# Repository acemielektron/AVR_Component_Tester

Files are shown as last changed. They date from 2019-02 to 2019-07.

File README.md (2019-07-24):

# AVR_Component_Tester
DIY single sided PCB for AVR Component Tester (based on pdf file by Karl-Heinz Kübbeler)

A very useful gadget whether you buy from many clones available or build it yourself. Here is my version:

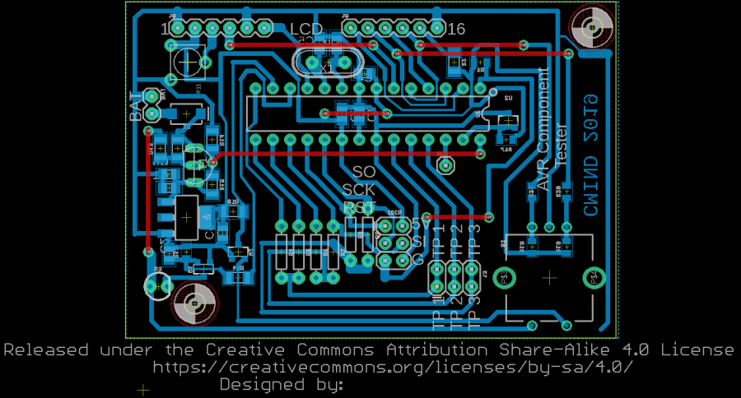
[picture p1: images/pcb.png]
pcb</img>

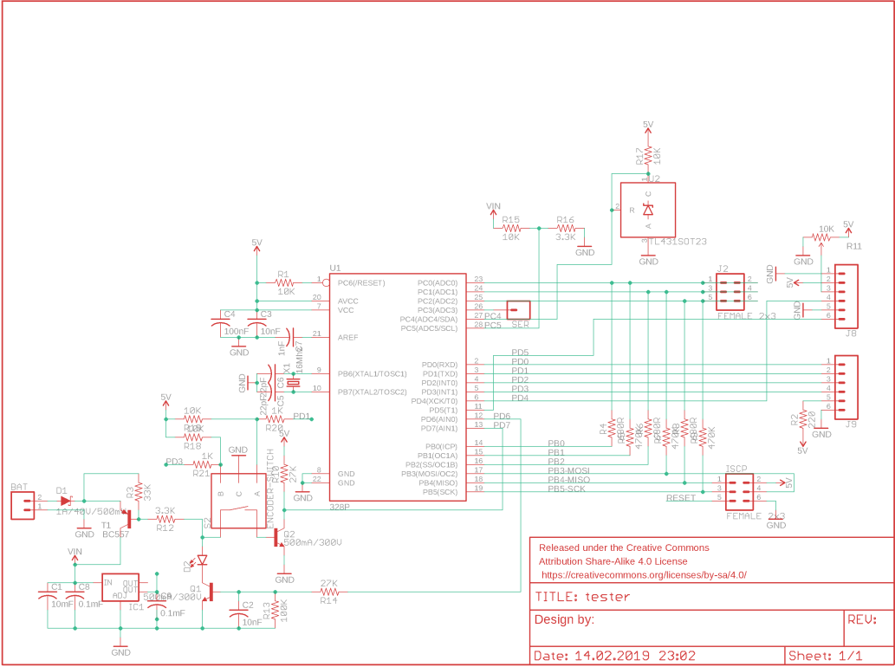
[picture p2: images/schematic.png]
schematic</img>

photos of built device:
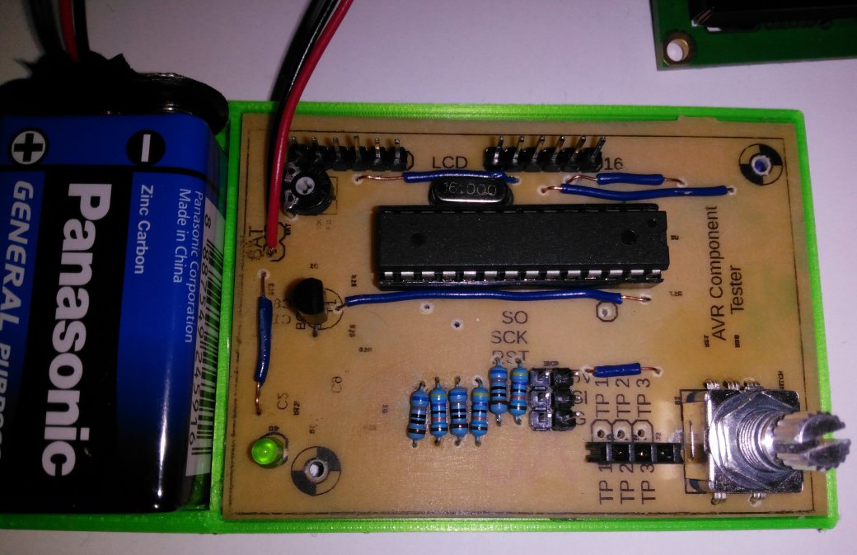
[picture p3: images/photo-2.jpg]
without 2x16 lcd screen</img>

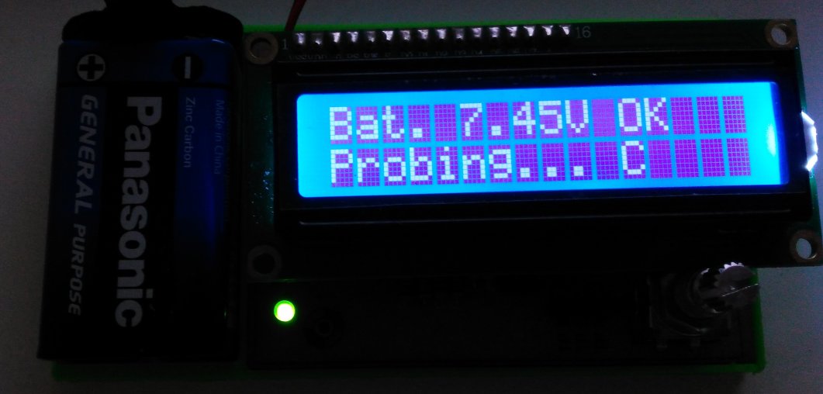
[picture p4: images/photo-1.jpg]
screen installed and working</img>

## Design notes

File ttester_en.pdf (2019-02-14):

# TransistorTester with AVR microcontroller and a little more Version 1.13k

### Karl-Heinz K¨ubbeler

kh kuebbeler@web.de

### March 8, 2018

# Contents

1 Features | 5
2 Hardware | 9
3 Instructions for use | 39
4 Configuring the TransistorTester | 48

5 Description of the measurement procedures | 60
5.1 Measurement of Semiconductors | 62
5.1.1 | Measurement of PNP Transistor or P-Channel-MOSFET | 63
5.1.2 | Measurement of NPN Transistor or N-Channel-MOSFET | 65
5.1.3 | Simplified flowchart of the transistors tests | 68
5.1.4 | Measurement of Diodes | 70
5.1.5 | Results of different measurements | 71
5.2 Resistor Measurement | 75
5.2.1 | Resistor Measurement with 680 Ohm Resistors | 75
5.2.2 | Resistor Measurement with 470 kOhm resistors | 77
5.2.3 | Results of the resistor measurements | 78
5.3 Measurement of Capacitors | 83
5.3.1 | Discharging of Capacitors | 83
5.3.2 | Measurement of big Capacitors | 83
5.3.3 | Measurement of small Capacitors | 86
5.3.4 | Measurement of very small capacity values with the sampling technique . . . . 88
5.3.5 | Measurement of the Equivalent Series Resistance ESR | 89
5.3.6 | Measurement of the Equivalent Series Resistance ESR, first way | 91
5.3.7 | Measurement of the Equivalent Series Resistance ESR, second way | 94
5.3.8 | Voltage loss after a load pulse, Vloss | 101
5.3.9 | Separate capacity and ESR measurement | 102
5.3.10 Results of Capacitor measurement | 103
5.3.11 Automatic calibration of the capacitor measurement | 107
5.4 Measurement of inductance | 111
5.4.1 | Results of the inductance measurements | 112
5.4.2 | Measurement of small inductances with the sampling method | 112
5.5 Selftest Function | 116
5.5.1 Some Results of the Selftest Function | 120
5.6 Measurement of frequency | 124
5.6.1 | Calibration of frequency with a GPS- or GLONASS-receiver | 125
5.6.2 | Calibration of the crystal frequency with a clock modul | 125
6 Signal generation | 127
6.1 Frequency Generation | 127
6.2 Puls width generation | 127
7 Known errors and unsolved problems | 128
8 Special Software Parts | 129
9 To Do List and new ideas | 130

## Preface

### Basically Motive

Every hobbyist knows the following problem: You disassemle a Transistor out of a printed board or you get one out of a collection box. If you find out the identification number and you already have a data sheet or you can get the documents about this part, everything is well. But if you don’t find any documents, you have no idea, what kind of part this can be. With conventional approach of measurement it is difficult and time-consuming to find out the type of the part and parameters. It could be a NPN, PNP, N- or P-Channel-Mosfet etc. It was the idea of Markus F. to hand over the work to a AVR microcontroller.

### As my work has started

My work with the software of the TransistorTester of Markus F. [1] has started, because I had problems with my programmer. I had bought a printed board and components, but I could not program the EEprom of the ATmega8 with the Windows driver without error messages. Therefore I took the software of Markus F. and changed all the accesses from the EEprom memory to flash memory accesses. By analysing the software in order to save memory at other places of program, I had the idea, to change the result of the ReadADC function from ADC units to millivolt (mV) units. The mV resolution is needed for any output of voltage values. If ReadADC returns directly the mV resolution, I can save the conversion for each output value. This mV resolution can be get, if you first accumulate the results of 22 ADC readings. The sum must be multiplied with two and divided by nine. Then we have a maximum value of 1023·22·2
9 = 5001, which matches perfect to the wanted mV resolution of measured voltage values. So I additionally had the hope, that the enhancement of ADC resolution by oversampling could help to improve the voltage reading of the ADC, as described in AVR121 [5]. The original version ReadADC has accumulated the result of 20 ADC measurements and divides afterwards by 20, so the result is equal to original ADC resolution. By this way never a enhancement of ADC resolution can take place. So I had to do little work to change the ReadADC, but this forced analysing the whole program and change of all “if-statements” in the program, where voltage values are queried. But this was only the beginning of my work!

More and more ideas to make measurement faster and more accurate has been implemented. Additionally the range of resistor and capacity measurements are extended. The output format for LCD-Display was changed, so symbols are taken for diodes, resistors and capacitors instead of text. For further details take a look to the actual feature list chapter 1. Planned work and new ideas are accumulated in the To Do List in chapter 9. By the way, now I can program the EEprom of the ATmega with Linux operating system without errors.
At this place I would like to thank the originator and software author Markus Frejek, who has enabled the continuation with his initial work. In addition I would like to say thanks to the authors of numerous input to the discussion forum, which have assist me, to find new tasks, weak points and errors. Next I would like to thank Markus Reschke, who give me the permission, to publish his cheerful software versions at the SVN server. Furthermore some ideas and software part of Markus R. was integrated in my own software version, again thank you very much. Also Wolfgang SCH. has done a great job to support a graphical display with ST7565 controller. Many thanks to him for integrating his patch for 1.10k software version to the actual developer version. I have to thank also Asco B., who has developed a new printed board, to enable the reproductions for other hobbyists. Another thank I would like to send to Dirk W. , who has handled the omnibus order for this printed board. Never I had time anough to handle these things concurrently with my software developement, at no time the state of further developement of software would have the same level. Thanks for the many suggestions to improve the tester to the members of the local chapter of the

”Deutscher Amateur Radio Club (DARC)” in Lennestadt. Also I would like to say thanks for the integration of the sampling method to the radio amateur Pieter-Tjerk (PA3FWM). With this method the measurement of little capacity and inductance values could be improved noticeable. Last but not least I would say thanks to Nick L. from Ukraine, who has supported my with his prototype boards, has suggested some hardware add ons and also has organized the russian translation for this description.

# Chapter 1

# Features

1. Operates with ATmega8, ATmega168 or ATmega328 microcontrollers. Additionally ATmega644, ATmega1284, ATmega1280 or ATmega2560 microcontrollers can be used.
2. Displaying the results to a 2x16 or a 4x16 character LCD-Display. If the processor have at least 32K flash memory, also a graphical display with 128x64 pixel and a ST7565, ST7920, NT7108, KS0108 or a SSD1306 controller can be used. In doing so a 4-wire SPI interface or a I

2C bus must be used instead of the 4-bit parallel interface for the SSD1306 controller. Even color displays with ILI9163 or ST7735 controller are usable with the SPI interface. For the NT7108 or KS0108 controller you must use a serial - parallel interface with a 74HC(T)164 or a 74HC(T)595. Displays with PCF8812 or PCF8814 controller can be only used without the big icons for transistors, because the display size is unsufficient (102x65 and 96x65).

3. One key operation with automatic power shutdown.
4. Battery operation is possible since shutdown current is only about 20nA.
5. Low cost version is feasible without crystal and auto power off. With software version 1.05k the sleep modus of the Atmega is used to reduce current if no measurement is required and no rotary encoder is used (not with ATmega8).
6. Automatic detection of NPN and PNP bipolar transistors, N- and P-Channel MOSFETs, JFETs, diodes, double diodes,N- and P-IGBTs, Thyristors and Triacs. For Thyristors and Triacs the ignition current and holding current must be reached with the tester. For IGBTs the 5V signal should be enough for driving the gate voltage.
7. Automatic detection of pin layout of the detected part.
8. Measuring of current amplification factor and Base-Emitter threshold voltage of bipolar transistors.
9. Darlington transistors can be identified by the threshold voltage and high current amplification factor.
10. Detection of the protection diode of bipolar transistors and MOSFETs.
11. Measuring of the Gate threshold voltage, the Gate capacity value and the RDSon at almost 5V gate voltage of MOSFETs.
12. Up to two Resistors are measured and shown with symbols | and values with up to four
decimal digits in the right dimension. All symbols are surrounded by the probe numbers of the Tester (1-3). So Potentiometer can also be measured. If the Potentiometer is adjusted to one of its ends, the Tester cannot differ the middle pin and the end pin.

13. Resolution of resistor measurement is now up to 0.01Ω, values up to 50MΩ are detected.
14. One capacitor can be detected and measured. It is shown with symbol | and value with
up to four decimal digits in the right dimension. The value can be from 25pF (8MHz clock, 50pF @1MHz clock) to 100mF. The resolution can be up to 1pF (@8MHz clock].
15. For capacitors with a capacity value above 20nF the Equivalent Serial Resistance (ESR) is measured with a resolution of 0.01Ω and is shown with two significant decimal digits. This feature is only available for ATmega with at least 16K flash memory.
16. For capacitors with a capacity value above 5000pF the voltage loss after a load pulse can be determined. The voltage loss give a hint for the quality factor of the capacitor.
17. Up to two diodes are shown with symbol | or symbol | in correct order. Additionally
the flux voltages are shown.
18. LED is detected as diode, the flux voltage is much higher than normal. Two-in-one LEDs are also detected as two diodes.
19. Zener-Diodes can be detected, if reverse break down Voltage is below 4.5V . These are shown as two diodes, you can identify this part only by the voltages. The outer probe numbers, which surround the diode symbols, are identical in this case. You can identify the real Anode of the diode only by the one with break down (threshold) Voltage nearby 700mV !
20. If more than 3 diode type parts are detected, the number of founded diodes is shown additionally to the fail message. This can only happen, if Diodes are attached to all three probes and at least one is a Z-Diode. In this case you should only connect two probes and start measurement again, one after the other.
21. Measurement of the capacity value of a single diode in reverse direction. Bipolar Transistors can also be analysed, if you connect the Base and only one of Collector or Emitter. If a ATmega with more than 8K flash memory is used, also the reverse current of the diode is measured with a resolution of 2nA. The value is only output to the screen, if it is greater than zero.
22. Only one measurement is needed to find out the connections of a bridge rectifier.
23. Capacitors with value below 25pF are usually not detectet, but can be measured together with a parallel diode or a parallel capacitor with at least 25pF. In this case you must subtract the capacity value of the parallel connected part. For processors with at least 32K flash memory the tester changeover to a special capacity meter function, if a capacitor with more than 25pF is once measured at TP1 and TP3. In this capacitor meter mode you can measure capacitors below 25pF at TP1 and TP3 directly.
24. For resistors below 2100Ω also the measurement of inductance will be done, if your ATmega
has at least 16K flash memory. For that a inductor icon | is shown behind the resistor
icon | . The range will be from about 0.01mH to more than 20H, but the accuracy is not
good. The measurement result is only shown with a single component connected.
25. Testing time is about two seconds, only capacity or inductance measurement can cause longer period.
26. Software can be configured to enable series of measurements before power will be shut down.
27. Build in selftest function with optional 50Hz Frequency generator to check the accuracy of clock frequency and wait calls (only for processors with at least 32K flash memory).

28. Selectable facility to calibrate the internal port resistance of port output and the zero offset of capacity measurement with the selftest (only for processors with at least 16K flash memory). A external capacitor with a value between 100nF and 20µF connected to pin 1 and pin 3 is necessary to compensate the offset voltage of the analog comparator. This can reduce measurement errors of capacitors of up to 40µF. With the same capacitor a correction voltage to the internal reference voltage is found to adjust the gain for ADC measuring with the internal reference.
29. Display the Collector cutoff current ICE0 with currentless base (1µA units) and Collector residual current ICES with base hold to emitter level (only for processors with at least 16K flash). This values are only shown, if they are not zero (especially for Germanium transistors).
30. For a ATmega with at least 32K flash memory the tester changes the operation modus from universal tester to a resistor tester, if only one resistor is detected at the test pin 1 (TP1) and test pin 3 (TP3). If you have selected the additional measurement of inductance for the resistor meter function with the Makefile option RMETER WITH L, also the inductance of components is measured in this mode. This special operating mode is indicated with a [R] or [RL] at the right side of the first display line. In the same way the tester changes to a capacity meter function, if a capacitor is detected at TP1 and TP3. This operation mode is indicated with a [C] at the right side of the first display line. With this capacity meter function capacity values are shown down to 1pF. Only for the automatic start you need a capacitor with more than 25pF. Both special modes can be finished by a key press. The tester will then continue with the normal tester function.
31. For processors with at least 32K flash a dialog function can be selected, which enable additional functions. Of course you can return from dialog to the normal Transistor Tester function.
32. With dialog function you can use a frequency measurement at port PD4 of the ATmega. The resolution is 1Hz for input frequencies above 33kHz. For lower frequencies the resolution can be up to 0.001mHz by measuring the mean period. You should read the the subsection Frequency measurement 2.2.4 at page 13 for details of connection a frequency signal.
33. With the dialog function and without the activated serial output a external voltage of up to 50V can be measured with the 10:1 voltage divider at the PC3 port. If the PLCC-Version of the ATmega328 is used, one of the additional pins can be used for the voltage measurement together with the serial output. If the zener diode measurement extension (DC-DC converter) is assembled, the measurement of zener diodes is also possible with this function by pressing the key.
34. With the dialog function a frequency output can be selected at the TP2 pin (PB2 Port of the ATmega). Currently frequencies from 1Hz up to 2MHz can be selected.
35. With the dialog function a fixed frequency output with selectable pulse width can be activated at the TP2 pin (PB2 port of the ATmega). The width can be enhanced with 1% by a short key press or with 10% by a longer key press.
36. With the dialog function can be started a separated capacity measurement with ESR measurement. Capacities from about 2µF up to 50mF can most be measured in circuit, because only a little measurement voltage of about 300mV is used.
37. If your ATmega has at least 32K flash memory (Mega328), you can also use the sampling method of the ADC, which can measure capacitors with less than 100pF at a resolution of up to 0.01pF. With the same method you can also measure coils with less than 2mH with significant better resolution of the inductance by building a resonant circuit with a parallel capacitor of known capacity value.

You should make sure, that all capacitors have no residual charge before starting any measurement, especially if you use the tester for measurement of capacitor in circuit.
Thyristors and Triacs can only be detected, if the test current is above the holding current. Some Thyristors and Triacs need as higher gate trigger current, than this Tester can deliver. The available testing current is only about 6mA! Also a IGBT can only be detected correctly, if a voltage of 5V is sufficient to drive the gate. Notice that many features can only be used with microcontroller with enough program memory such as ATmega168. Only processors with at least 32k flash memory like ATmega328 or ATmega1284 can take all features.

Attention: Allways be sure to discharge capacitors before connecting them to the Tester! The Tester may be damaged before you have switched it on. There is only a little protection at the ATmega ports.
Extra causion is required if you try to test components mounted in a circuit. In either case the equipment should be disconnected from power source and you should be sure, that no residual voltage remains in the equipment.

# Chapter 2

# Hardware

## 2.1 Circuit of the TransistorTester

The circuit of the TransistorTester in figure 2.1 is based on the circuit of Markus F. released in Abb. 1 of AVR-Transistortester report [1]. Changed or moved parts are marked with green color, optional parts are marked with red color.
Some changes are made because the electronical power switch make problems in some implemen-tations. Therefore the resistor R7 is reduced to 3.3kΩ. The capacitor C2 is reduced to 10 nF and R8 is moved so that the PD6 output does not try to switch the C2 capacitor directly. Additional blocking capacitors are added and should be placed near the power connection of the Atmega and near the Voltage regulator.
Because the PD7 input and PC6 (RESET) are the only pins, where pull up resistors where needed, one extra 27kΩ resistor is added to the PD7 (pin 13) input. With this modification the software can disable all internal pull up resistors of the ATmega.
The additional crystal with its 22pF capacitors are optional added. The accuracy of a crystal has the benefit of more stable time measurement for getting the capacitor values.
New software version can use a voltage scale switch of the ADC. The speed of switching is reduced by the external capacitor C1 at the AREF (21) pin of the ATmega. To avoid slowing down the measurement speed more than necessary, the value of this capacitor should be reduced to 1nF. Removing of the capacitor C1 is also possible. For adapting the software to the actual circuit take a look to the Makefile options in the configuring chapter 4 at page 48.
Some different versions of R11 / R12 resistor combinations circulates in the internet. I have adapted my software to the original of Markus F. [1] with 10kΩ and 3.3kΩ. The voltage ration of the divider can be set with Makefile options.
The additional 2.5V precision voltage reference connected at pin PC4 (ADC4) can be used to check and calibrate the VCC voltage, but is not required. You can use a LM4040-AIZ2.5 (0.1%), a LT1004CZ-2.5 (0.8%) or a LM336-Z2.5 (0.8%) as voltage reference. If you don’t install the precision voltage reference and you don’t add the relay extension, you should install a pull up resistor R16 to PC4 with a higher resistance value (47kΩ). This helps the software to detect the missing voltage reference. A optional ISP connector has been added to easier load new software versions to the tester.

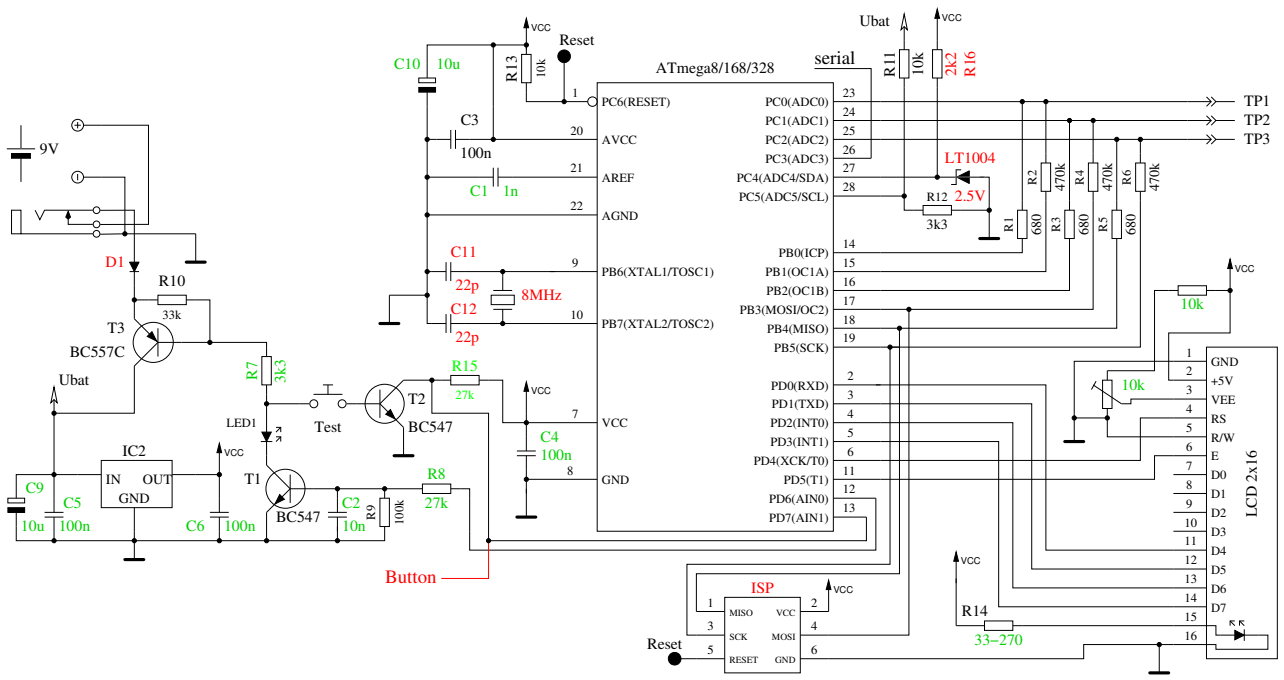
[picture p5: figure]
OUT; GND; PB7(XTAL2/TOSC2); PC6(RESET); PD7(AIN1); PD6(AIN0); PD4(XCK/T0); PD3(INT1); PD2(INT0); PD1(TXD); PD0(RXD); PB4(MISO); PB5(SCK); PB3(MOSI/OC2); PB0(ICP); PC0(ADC0); PC1(ADC1); PC2(ADC2); PC3(ADC3); PC4(ADC4/SDA); PC5(ADC5/SCL); AREF; PB6(XTAL1/TOSC1); ATmega8/168/328; VCC; AVCC; AGND; 8MHz; Ubat; LCD 2x16; VEE; Test; LED1; 1 MISO; SCK; RESET; MOSI; ISP; Reset; serial; Button

Figure 2.1. New circuit of TransistorTester

The table 2.1 show the assignment of the port D for different display versions and the assignment of the additional functions. For the SPI interface a signal LCD-CE is available at the ATmega port. The controller input CE (Chip Enable) can be also connected to GND instead of connecting this input to the ATmega output LCD-CE.

Port | Character LCD | ST7565 LCD SPI | ST7920 LCD serial | NT7108 LCD serial | SSD1306 I 2C | additional function
PD0 | LCD-D4 | LCD-REST | LCD-REST | 595-PCLK
PD1 | LCD-D5 | LCD-RS | | LCD-CS2 | | rotary encoder 2
PD2 | LCD-D6 | LCD-SCLK | LCD-B0 | 164-595-CLK | LCD-SDA
PD3 | LCD-D7 | LCD-SI | | LCD-CS1 | | rotary encoder 1
PD4 | LCD-RS | | | LCD-RS 164-595-SER | | frequency counter
PD5 | LCD-E | (LCD-CE) | LCD-EN | LCD-EN | LCD–SCL
PD7 | pushbutton | pushbutton | pushbutton | pushbutton | pushbutton

Table 2.1. Pin assignments for different displays

The software can follow to another pin assignment of port D for a simpler connection of the LCD display. The following table 2.2 shows the modifies assignments for the strip grid layout and the alternativ connection of a graphical display for the micocontrollers ATmega328. Also the using of port inputs for additional functions is shown. With the connections for the graphical display with the strip grid option (STRIP GRID BOARD=1) the frequency counter function can not be used, because the port PD4 (T0) is used. But this connection is used by a chinese version with graphical display. In most cases the additional functions like rotary encoder or frequency counter are easier to build with the board versions for a character display, because the required data signals are routed to the display connector.

Port | char. LCD =1 | ST7565 LCD =1 | ST7565 LCD STRIP GRID | additional function
PD0 | pushbutton
PD1 | LCD-D7 | LCD-SI | LCD-A0 (RS) | rotary encoder 2
PD2 | LCD-D6 | LCD-SCLK | LCD-REST
PD3 | LCD-D5 | LCD-A0 (RS) | LCD-SCLK | rotary encoder 1
PD4 | LCD-D4 | LCD-REST | LCD-SI | frequency counter
PD5 | LCD-E | (LCD-CE)
PD7 | LCD-RS | pushbutton | pushbutton

Table 2.2. port assignments with option STRIP GRID BOARD

## 2.2 Extensions for the TransistorTester

### 2.2.1 Protection of the ATmega inputs

For better protection of the ATmega inputs one of the additional circuits 2.2 can be integrated. The de-energized contacts of the relay protect the ATmega without power. The contacts will be opened by software only for measurement. Also with the additional diode protection the chance of the ATmega will be better to survive the connection of a capacitor with higher residual voltage. A complete protection is not possible. Therefore capacitors should always be discharged before measuring.

TP2
TP3

TP1

4k7

BC547

PC0(ADC0)
PC1(ADC1)
PC2(ADC2)

PC4(ADC4/SDA)

or Ubat
depending of relay type

VCC

(a) with Relay

P6KE6V8A

5

2

1 | 3 | 4 | 6

SRV05−4

TP1
TP2
TP3

100nF

VCC

(b) with Diodes

Figure 2.2. Additional protection of the ATmega inputs

You can get a better protection with a relay with 3 changeover contacts, which is shown in figure 2.3. The discharge current is limited with the resistors and the ATmega-inputs are disconnected in the protected mode. But you don’t forget, that the tester remains unprotected during the measurement sequence.

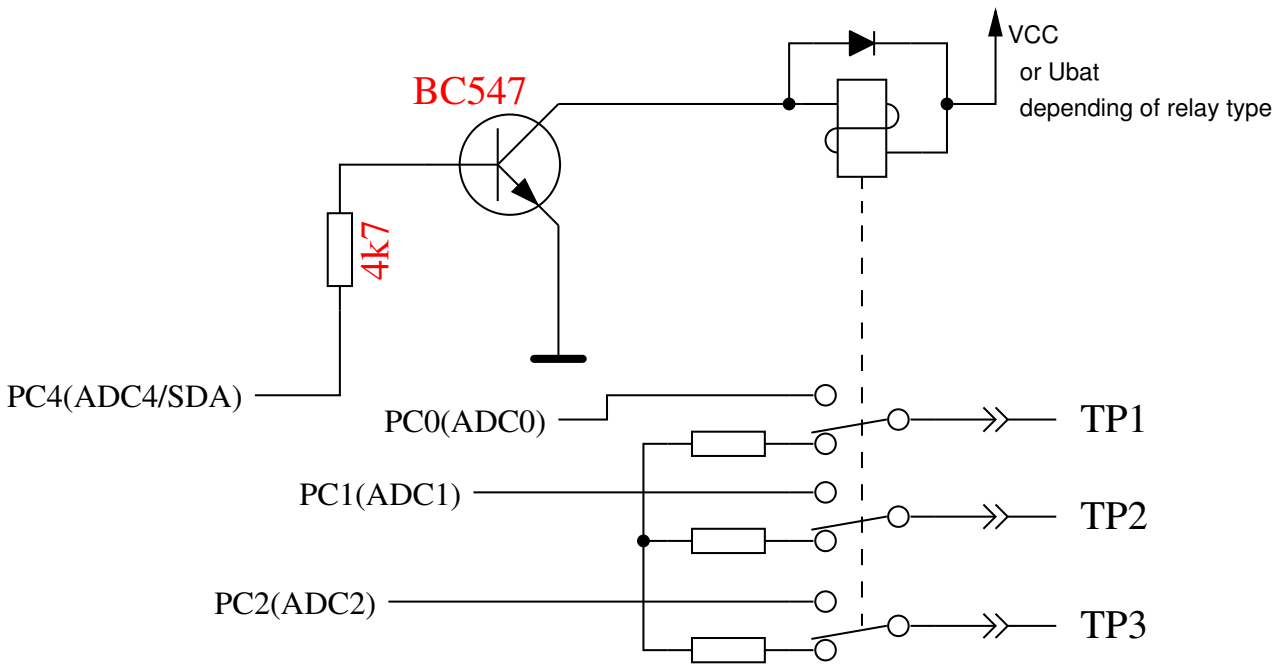
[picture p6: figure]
PC0(ADC0); PC4(ADC4/SDA); TP3 PC2(ADC2); PC1(ADC1); depending of relay type; or Ubat; VCC

3x10

Figure 2.3. Improved protection with relay

### 2.2.2 Measurement of zener voltage above 4 Volt

If the serial output of text is not required, the Pin PC3 of the ATmega can be used as analog input for measuring a external voltage. The voltage can be up to 50V with the optional 10:1 resistor divider and can be used for measuring the breakdown voltage of a zener diode. A current limiting power supply with up to 50V can be switched on with low signal at PD7 pin of the ATmega to deliver current for testing the break down voltage of a zener diode. Figure 2.4 shows a suggestion for this expansion. The tester shows the external voltage as long as you hold the key pressed. About 40mA more battery current is used by this expansion during key pressing.

Vin+

Vin−

Com DC−DC Conv.

Vout+15

Vout−15

R18

180k

R17

20k

10n

serial / PC3

External
Voltage

1uF

33uH

L1

C13

Uext
10k

TMA0515D

T4
Uext

Button

R19

Ubat

C15

100n

Can be placed on Tester board! Should be placed separate!

IN OUT

IC3

GND

MCP1702

IRFU9024

C17

C16

50u 100n
C14

Figure 2.4. Expansion for measuring of break down voltage of Zener diodes

The 10:1 voltage divider can be used with the optional dialog part for the ATmega328 without the activated DC-DC converter for the zener diode measurement. Without the pressed key the voltage converter is not powered. For that the external voltage (for example battery voltage) can be measured at the zener diode port. You can only measure positiv DC voltages up to 50V . You have also to respect the correct polarity.

### 2.2.3 Frequency generator

With the dialog part of the ATmega you can also select a frequency generator, which supports currently a selection of frequencies from 1Hz up to 2MHz. The output of the 5V signal is done with a 680Ω resistor to test port TP2. You can use the GND signal from the minus pin of the zener diode extension or the test port TP1. The test port TP3 is connected to GND with a 680Ω resistor. Of course you can also connect a driver circuit to the ATmega port PB2 with a separate output driver circuit and a additional output terminal. But the input of this circuit should not insert a big capacity load for the ATmega output.

### 2.2.4 Frequency measurement

For using the with the dialog selectable frequency measurement is a little hardware extension necessary. The input pin PD4 (T0/PCINT20) of the ATmega is used for the frequency measurement. The same pin is also used for the connection of the LCD. With normal layout, the PD4 pin is connected to the LCD-RS signal, with the strip grid design it is connected to LCD-D4. For both signals the PD4 pin can be switched to input as long as no output to the LCD is required. The LCD respect the input value only, if the LCD-E signal is switched to GND. For driving the input pin from external clock source at least one serial resistor of 270Ω should be used. Better you should use the circuit of figure 2.5 . The voltage at the PD4 pin (LCD-RS or LCD-D4) should be adjusted to 2.4V without the assembled ATmega or during frequency measurement of the ATmega, to get the best sensivity for the input frequency signal. The LCD should always be installed for adjusting, because the pull up resistor of the LCD change the voltage.

Figure 2.5. Extension for measurement of frequency

### 2.2.5 Using of a rotary pulse encoder

For easier control of the menu function for the ATmega328 you can expand the circuit by a rotary pulse encoder with a push button. The circuit 2.6 shows a standard expansion for a normal character LCD. All signals for the connection of the rotary pulse encoder are available at the plug connector for the LCD. For this reason the expansion can also be easy upgraded for many existing testers. In many cases the graphical LCD is assembled on a adapter board with some connection pins of the character LCD. Also in this cases the upgrade with a rotary encoder is not very difficult to do.

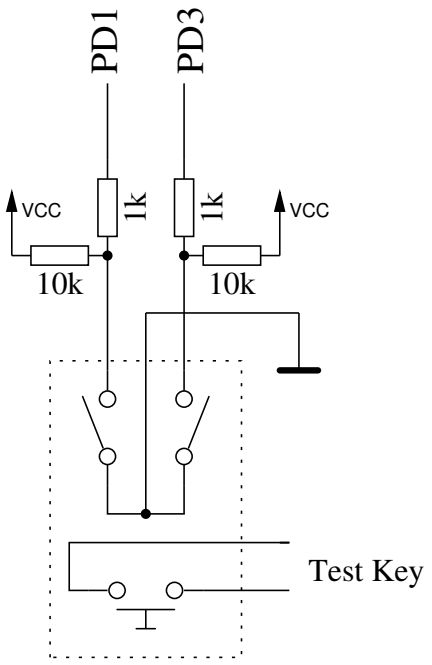
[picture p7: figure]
1k PD¹; PD³; Test Key; VCC

Figure 2.6. Expansion with a rotary pulse encoder

The figure 2.7 shows the feature of two different rotary pulse encoder. The version 1 has twice as much indexed positions (detents) per turn as pulses per turn. The version 2 has the same count of detents as pulses per turn. The slope of one of the two switch signals is sometimes exactly at the detent of the rotary pulse encoder.

Switch A

Switch B

detent | detent | detent
State: | 2 | 0 | 1 | 3 | 2 | 0 | 1 | 3 | 2 | 0 | 1 | 2 3

L

H

L

H

Version 1

detent | detent | detent

Switch A

Switch B

detent | detent | detent
2 | 0 | 1 | 3 | 2 | 0 | 1 | 3 | 2 | 0 | 1 | 2 3

Version 2

State:

L

H

L

H

Figure 2.7. Feature of two different rotary pulse encoder

The figure 2.8 shows a rotary pulse encoder, which has not only bouncing contacts, but also has a unstable state of one of the switches at the indexed position (detent). Every change of the state of the switches is detected by the program and saved in a cyclic buffer. Therefore the last three states of the switches can be checked after every status change. For every cycle of switch states a total of four sequences of state can be defined for every direction of rotation. If there is only one indexed position (detent) for every cycle of switch states, only one of the state sequence pair must be monitored (WITH ROTARY SWITCH=2 or 3) for correct counting. If there are two indexed positions for every cycle of the switch states, as shown in figure 2.8, you must monitor two pairs of switch state sequences (WITH ROTARY SWITCH=1). You can choise any resolution for the WITH ROTARY SWITCH for a rotary pulse encoder without indexed positions. A value of 2 or 3 selects the lowest resolution, 1 selects a middle resolution and 5 selects the highest resulution. A oscillation of the selection (counter up, counter down) can be avoided with the type of monitoring, but sometimes a count can be missed with a bad placement of the indexed position.

H

L

2 | 3 | 0 | 2

Switch A

Switch B

H

L

0

detent 1 | detent 2
State:

detent 3

Possible state history from left to right:

0 | 2020 | 2 | 3232 | 3 | 0 | 2 1313 | 0101 | 2020

1

1

023 = − | 310 = −
320 = + | 013 = +

231 = −
132 = +

102 = −
201 = +

Figure 2.8. A rotary pulse encoder with bouncing switches

In place of the two switches of a rotary switch encoder you can also install two seperate key buttons for Up and Down movement, if no rotation switch encoder is present or favored. In this case the option WITH ROTARY SWITCH must be set to 4 for a correct handling of the program.

### 2.2.6 Connection of a graphical display

Many thanks to Wolfgang Sch. for his work to support a chinese version with ST7565 controller. By now you can also connect a graphical 128x64 pixel LCD with a ST7565 controller. Because the ST7565 controller is connected with a serial interface, only four signal lines are required. Two port D pins of the ATmega can be used otherwise. The ATmega processor should have at least 32k flash memory for the support of a graphical display. The ST7565 controller works with a operating voltage of 3.3V . Therefore a additional 3.3V voltage regulator is required. The data sheet of the ST7565 controller does not allow the direct connection of input pins to 5V signal level. So the extension of figure 2.9 uses a additional 74HC4050 CMOS device for the conversion of the voltage level. You can try to exchange the four 74HC4050 gates with four resistors of about 2.7kΩ. With the voltage drop at the resistors you will prevent the increase of the 3.3V controller power voltage across the diodes of the controller inputs from the 5V ATmega outputs signals. You have to try, if the signal form with the resistors can be accepted from the ST7565 controller inputs. The signal form at the controller inputs will be more simular to the output shape of the ATmega with the 74HC4050 gates in any case.

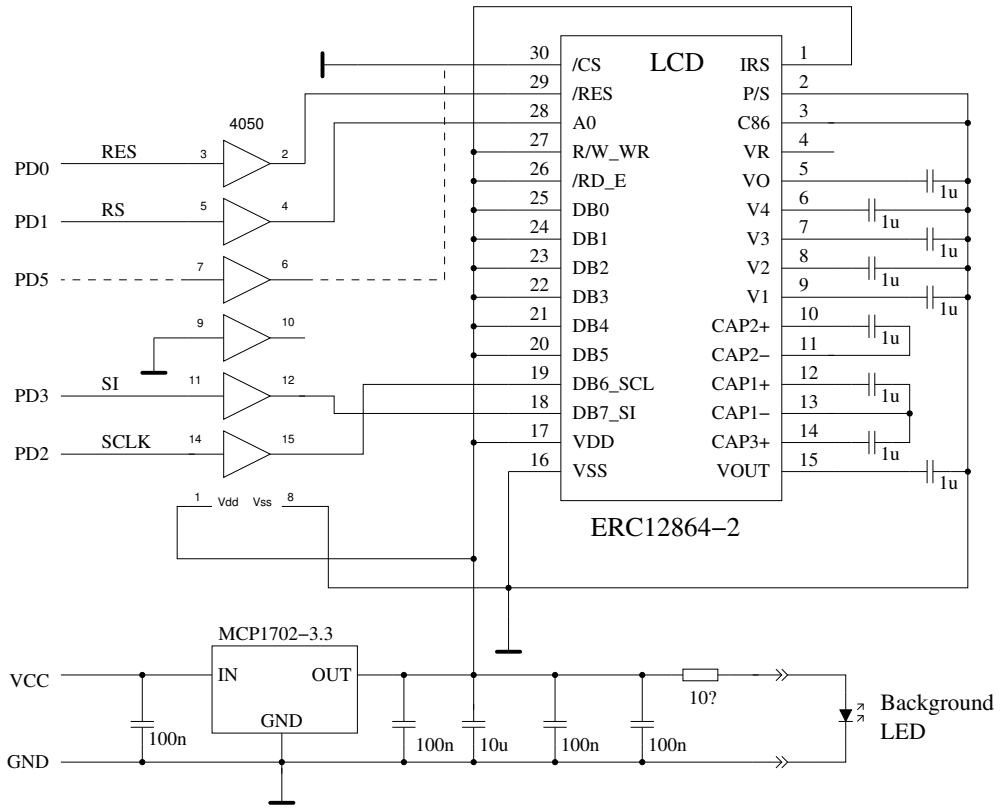
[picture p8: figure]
IRS; VOUT; CAP3+; CAP1−; CAP1+; CAP2−; CAP2+; ERC12864−2; LCD ³⁰; VSS; VDD; DB6_SCL; /RES; MCP1702−3.3; OUT; GND; VCC; RES; SCLK; LED; Background; Vss; 8 Vdd 1

Figure 2.9. Connection of a graphical display with ST7565 controller

The table 2.3 shows more alternativs to connect a ATmega328 or other prozessors with the SPI (LCD INTERFACE MODE=4) or the 3LINE (LCD INTERFACE MODE=3) interface. The different connector lists for one processor type can be selected with the Makefile Option STRIP GRID BOARD. The connector pin list is defined in the file config.h. If you need a different wiring list, you should choose a new code number for the option STRIP GRID BOARD and supplement the setting in the config.h file.

Processor STRIP GRID BOARD | m644 | m1280 - | m1280 1 | m328 - | m328 1 | m328 2 | m328 5
Signal: RES | PB4 | PA0 | PA4 | PD0 | PD4 | PD0 | PD2
EN, CLK | PB6 | PA2 | PA2 | PD2 | PD2 | PD2 | PD3
RS, D/C | PB5 | PA1 | PA3 | PD1 | PD3 | PD3 | PD1
B0, MOSI | PB7 | PA3 | PA1 | PD3 | PD1 | PD1 | PD4
CE, CS | PB3 | PA4 | PA5 | PD5 | PD5 | PD5 | PD5

Table 2.3. SPI wiring facility for different processors

Normally the ST7565 or SSD1306 controller is connected with a 4-wire SPI interface. But with the SSD1306 controller you can also use a I²C interface with PD2 as SDA and PD5 as SCL signal. The SDA and SCL signals must be equipped with pull-up resistors of about 4.7kΩ to 3.3V . A solution for connecting the OLED display shows the figure 2.10. The outputs of the ATmega is only switched to 0V for the I²C signals. Before connecting the pull-up resistors to 5V you must check, if your display module can tolerate a 5V signal level. Normally the data inputs of the controller are protected with diodes to 3.3V . You should make sure, that you have loaded a program with the I²C support to the ATmega before the Display is connected. If you have loaded a program with another interface, the output are also switched to the 5V side. Because I have determined a influence to the tester results across the VCC connection of a OLED module, a additional decoupling with a serial resistor of 68Ω with a additional 10µF blocking capacitor is recommended. Instead of the 68Ω resistor you can also use a inductor with about 1mH. Without the additional filter my tester has reported collector residual currents with bipolar transistors and a OLED display. Also you should check the pin sequence of your OLED module, some moduls have a different location of GND and VCC.

and 3.3V regulator

128x64 OLED modul
with SSD1306 controller

SCL

GND

SDA

VCC

and 3.3V regulator

128x64 OLED modul
with SSD1306 controller

SCL

GND

SDA

IN | OUT | 3V3

GND

3.9k

PD5

PD2

3.9k

GND | 100nF 3.9k

3.9k

PD2
PD5
VCC | 68

10u

GND

VCC

68

MCP1702−3302

10u
100nF

LDO

Figure 2.10. Connection of a graphical OLED display with I²C interface

For connection to the ATmega644 series of processors the pins PB3 (SCL) and PB4 (SDA) instead of PD5 and PD2 are used. For the ATmega1280 processor series the pins PA5 (SCL) and PA4 (SDA) are used. The exchange of a text display to a graphical display is possible with a adapter printed board because all required data signals and power signals are available at the LCD connector.
A little simpler is the connection of a graphical display with a ST7920 controller because the controller can operate with 5V power voltage. For that the display should offer 128x64 visible pixels. The display module with the ST7920 controller can be connected with the 4-bit parallel interface or with a special serial interface., as shown in figure 2.11.

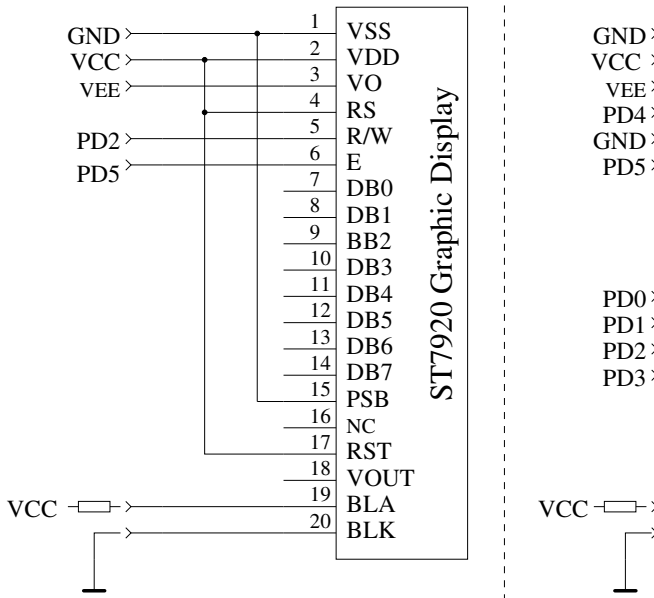
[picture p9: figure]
VSS; VDD VO RS R/W E; PSB; RST VOUT; BLK; BLA; ST7920 Graphic Display; GND VCC; VCC; VEE; GND
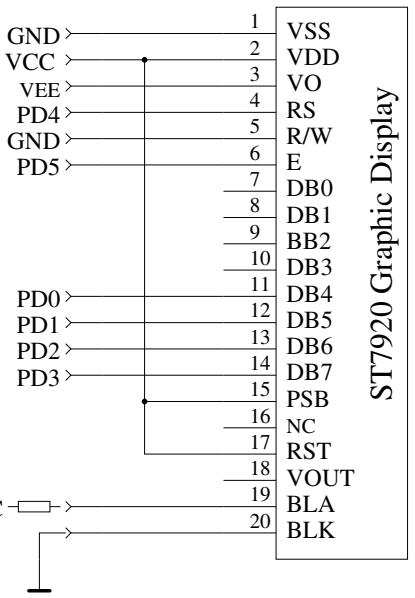
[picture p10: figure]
VSS; VDD VO RS R/W E; PSB; RST VOUT; BLK; BLA; ST7920 Graphic Display

serial mode | 4−bit parallel mode

Figure 2.11. Connection of a display with ST7920 controller

For both connection types the software must be configured in a special way. The Makefile option ”WITH LCD ST7565 = 7920” must be set in any case, for the serial connection type you must set also the option ”CFLAGS += -DLCD INTERFACE MODE=5”. The table 2.4 shows the connection of the serial signals with the INTERFACE MODE 5 (ST7920) and 7 (SSD1803) for different processors.

Processor STRIP GRID BOARD | m644 - | m644 1 | m1280 | m328
Signal: EN | PB3 | PB6 | PA5 | PD5
B0, R/W | PB4 | PB7 | PA4 | PD2
RESET | PB2 | PB4 | PA0 | PD0

Table 2.4. Serial connection for different processors

The orientation of the presentation can be changed with the options LCD ST7565 H FLIP and LCD ST7565 V FLIP in the same way as with the other graphical displays.

A special case is the connection of displays with a NT7108 (KS0108, S6B0108) controller. Because these displays can only use the 8-bit parallel interface, you must use a serial to parallel converter. The simplest way seems to be the use of a 74HCT164 or a 74HCT595 chip. A suitable suggestion of a connection circuit shows the figure 2.12 .

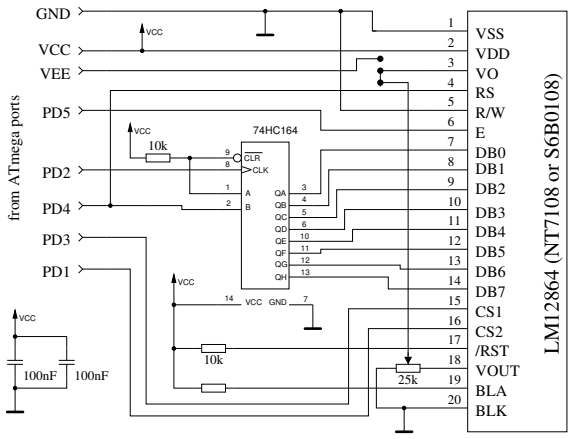
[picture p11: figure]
VSS VDD VO RS R/W E DB0 DB1 DB2; DB3 DB4 DB5 DB6 DB7 CS1 CS2 /RST VOUT BLA BLK; VCC; VEE; GND; from ATmega ports; CLR; CLK; 7 VCC

(a) with 74HCT164
(b) with 74HCT595

Figure 2.12. Connection of a graphical display with a NT7108 controller

You must check the pin layout of your LCD module, some moduls have different signal sequence. Some different pin layouts found in data sheets for the ABG128064 series are shown in table 2.5.

Signal | 128064H | 128064G | 128064C | 128064B
VDD (5V) | 1 | 2 | 4 | 2
VSS (GND) | 2 | 1 | 3 | 1
VO (Drive) | 3 | 3 | (5) | 3
DB0-DB3 | 4-7 | 7-10 | 9-12 | 7-10
DB4-DB7 | 8-11 | 11-14 | 13-16 | 11-14
CS1 CS2 | 12 13 | 15 16 | 1 2 | 15 16
Reset | 14 | 17 | - | 17
R/W | 15 | 5 | 7 | 5
RS | 16 | 4 | 6 | 4
E | 17 | 7 | 8 | 6
VEE | 18 | 18 | - | 18
LEDA LEDK | 19 20 | 19 20 | 17 18 | (19) -

Table 2.5. Pin layout of different NT7108 moduls

The table 2.6 shows the connection of a serial NT7108 controller for different processor series.

Processor | m644 | m1280 | m328
Signal: EN | PB3 | PA5 | PD5
RS B0 | PB2 PB2 | PA4 PA4 | PD4 PD4
CS1 | PB7 | PA3 | PD3
CS2 | PB5 | PA1 | PD1
CLK | PB6 | PA2 | PD2
PCLK | PB4 | PA0 | PD0

Table 2.6. Serial NT7108 connection for different processors

You can also use a display with a PCF8814 controller, which is usualy used in a Nokia 1100 handy for example. You must check, which interface of the controller is used in your display module. The PCF8814 controller can support the SPI-interface with 3 lines and 4 lines, the I²C-interface and a special 3-line interface, which receice the data/instruction signal as first serial bit before the 8 data bits. Because the display support only 96x65 pixels, the big icons for transistors are not used with this controller. The output is simular to the character display. As with the most graphical displays this controller also operated with 3.3 Volt. Therefore a signal conversion for the 5V outputs of the ATmega is required. For the SPI interface and the 3-line interface you can use the outputs of the ATmega like ”open collector” outputs with the Makefile option LCD SPI OPEN COL. You must use ”Pull-Up” resistors with this option or you should not set the option PULLUP DISABLE in the Makefile. Currently only the 3-line interface is tested with the PCF8814 controller.

Port | PCF8814 SPI | PCF8814 3-line | PCF8814 2C I | additional function
PD0 | LCD-RESet | LCD-RESset
PD1 | LCD-D/C | LCD-SCE | | rotary encoder 2
PD2 | LCD-SCLK | LCD-SCLK | LCD-SDIN
PD3 | LCD-SDIN | LCD-SDIN | | rotary encoder 1
PD4 | | | | frequency counter
PD5 | | LCD-EN | LCD-SCLK

Table 2.7. Pin assignments for different interface types of the PCF8814 controller

Some code for supporting a PCF8812 controller with 102x65 pixels is also implemented, but not yet tested.

### 2.2.7 Connection of a graphical color display

Some Chinese salesmen offer cheap color display modules with a SPI interface. The picture 2.13 shows the backsides of two supported modules with 128x128 pixel and 128x160 pixel. The moduls are very small, so the shown text and symbols are very little. But the appearance is sharp and clear.

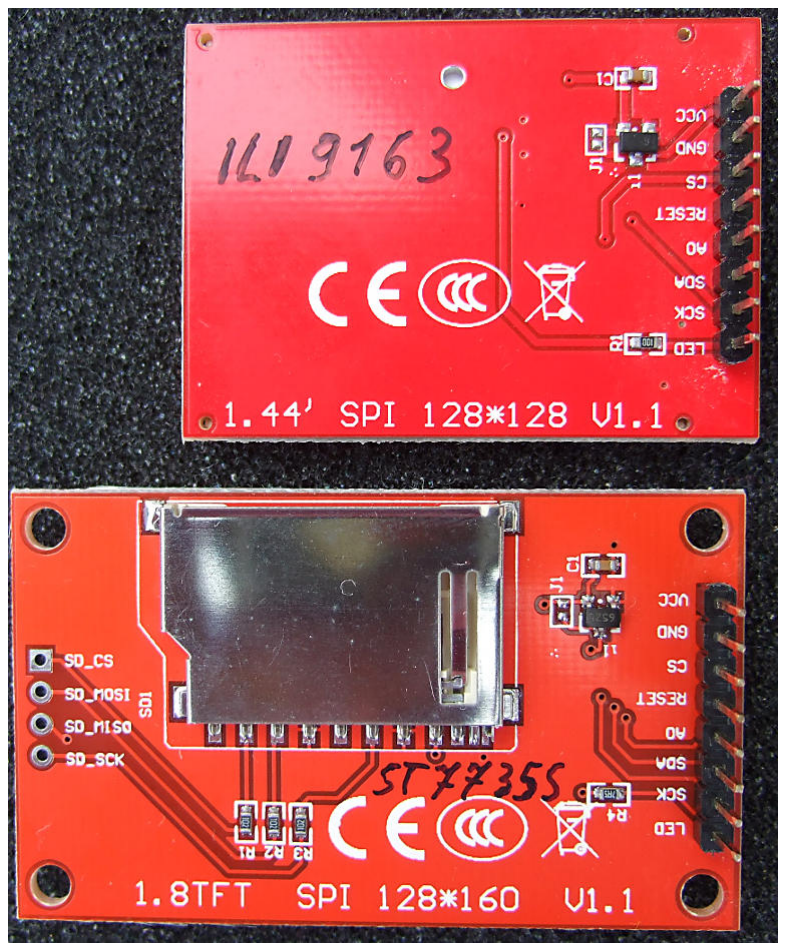
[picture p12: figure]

Figure 2.13. Back side of two Color-LCD’s

The 128x128 pixel modul uses a ILI9163 controller. The 128x160 pixel modul uses a very simular ST7735 controller. The modules are tested with a adapter board, which connects the SPI signals and the power to the terminal for the normal character display. The adaption of the 5V output signals of the ATmega to the 3.3V inputs of the controller is ensured with serial 10kΩ resistors. The background light (LED) is required for this modules because nothing is readable without it. Because of the high count of pixels in vertical direction you can display more text lines for this modules. For the 128x128 pixel display you can display 8 lines of text with a 12x8 font, for the 128x160 pixel display you can evel show 10 lines of text. At the picture 2.14 you can see the result of the measurement of a Germanium transistor at a 128x128 pixel display.

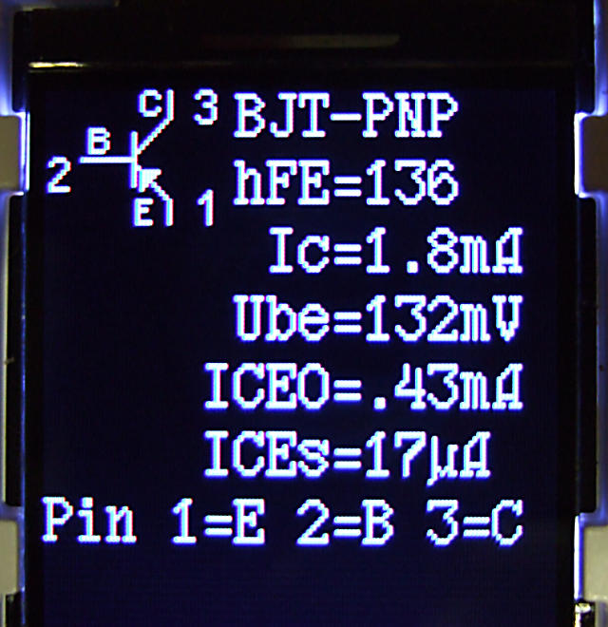
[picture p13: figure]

Figure 2.14. Measurement of a bipolar PNP transistors

The color feature of the modules is currently not used. Simply the background color and the foreground color can be changed in the file lcd defines.h or in the Makefile. The 16-bit color model of the controller is used by the software, the foreground color can be changed with the constant LCD FG COLOR and the background color with the constant LCD BG COLOR .

## 2.3 Hints for building the TransistorTester

Every LCD-display with at least 2x16 character and a HD44780 compatible controller can be used with the TransistorTester. You should respect the current needed for illumination, some LCD need lower current than others. I had tried OLED type displays, but this type cause interference with measurements of the ATmega and are not recommended. Also loading of special characters for displaying the resistor symbol has caused problems with the OLED.
The resistors R1 to R6 are critical for measurements and this 680Ω and 470kΩ resistors should be measurement type resistors (tolerance of 0.1%) to get the full accuracy. You should use a precision socket for the ATmega microcontroller to enable the replacement of the microcontroller. The microcontroller ATmega8, ATmega168 and ATmega328 can be used. Recommended is a ATmega328, if you wish to use all features.
Anyway you should assemble all parts to printed board without the microcontroller. A up-to-date low voltage drop regulator like MCP1702-5002 is recommended as IC2, because it need only 2µA of standby current and can still deliver 5V , if your input voltage is only 5.4V . But this part is not pin compatible to well known 78L05 with TO92 body!
After checking, that all needed parts are at the correct place, you should first connect the battery or power supply to the printed board without LCD-display and microcontroller. You should check the voltage at the power pins of the microcontroller and LCD-display terminal during the Test key is pressed. The voltage should disappear, if you release the Test key. If the voltage had correct polarity and value, you should disconnect the power and assemble the microcontroller with correct alignment. Be careful and make sure, that all pins of the microcontroller are in the socket holes. Now you can also connect the LCD. Check if power pins of the LCD has the right connection to GND and VCC of your board.
If you are sure that everything is all right, reconnect the power. If you have already programmed the ATmega, you can press the Test button. By pressing the Test key, the background light of the LCD should switch on. If you release the Test button, the LED should illuminate weak. Notice, that the software for the microcontroller must be compiled for the correct processor type. A program for the ATmega8 does not run on a ATmega168!

2.4 Changeover for tester versions designed by Markus F.

Voltage control If the problem exist, the tester will shut down immediately with every switch on. With imy suggested setting of the fuses (Makefile) the voltage control of the different ATmega versions is switched to 4V (brown out level). This may be the reason why the tester makes trouble with the power on sequence. The Pin PD6 tries to switch the 100nF capacitor C2 to VCC level causing a voltage breakdown of the VCC voltage (5V ). The capacitor C2 can be reduced to < 10nF without problems. If possible, the direct connection of PD6 should be replaced by a resistor > 220Ω.

Improvement of power on circuit Often this problem is the reason, if the tester starts with the button hold pressed, but switch off directly by releasing. The problem is enforced by a high current background light for the LCD. The resistor R7 to the base of the PNP transistor T3 was optimized with the value 27kΩ too much to save power consuming. To improve the switching with lower battery voltage or lower current amplification factor of the PNP transistor T3, you should reduce the resistance to 3.3kΩ.

Additional pull-up resistor at PD7 The missing pull-up resistor results to a switch off of the tester with the message ”Timeout” after a short display time. The software is configured with the option PULLUP DISABLE, that all internal pull-up resistors are switched off. For that reason the voltage of pin PD7 is not definded, if the level is not switched by the push button or transistor T2 to GND. One external pull-up resistor of 27kΩ to VCC avoid this error.

Capacitor C1 at the AREF pin Many designs use a 100nF capacitor at the AREF pin, like the design of Markus F. too. As long as the reference voltage of the ADC is never changed, this is a good solution. The software of the TransistorTester for the ATmega168/328 uses a automatic selection of the internal 1.1V reference voltage of the ADC, if the input voltage is below 1V . With this solution a better resolution of the ADC can be reached for little input voltages. Unfortunately the switching from 5V to 1.1V reference is very slowly. A additional wait time of 10ms must be respected for this reason. With changing the capacity value to 1nF this wait time can be reduced significant. I have not noticed any degration of measurement quality with this change. Even a removing of the capacitor has no significant change of measurement results. If you prefer to leve the capacitor unchanged, you can remove the option NO AREF CAP in the Makefile to activate longer wait times in the program.

Expanding of a 8MHz crystal With some skill you can expand a 8MHz crystal to the backside of the printed board directly to the pins PB6 and PB7 (pin 9 and pin 10). My own expansion was done without the both 22pF capacitors. This solution has operated well with all tested ATmega. But it is not required to use a crystal. You can still use the 8MHz RC oszillator by setting the fuses to get the better resolution of time constant for measuring the capacity values.

Smoothing of the operating voltage The original circuit of Markus F. shows only one 100nF capacitor to block the VCC voltage. This is clearly too little smoothing. You should at least use one 100nF near the ATmega power pins and one near the voltage regulator. The input of the voltage regulator should be blocked with a 100nF too. Additional 10µF capacitors (electrolytic or ceramic) at the input and output of the voltage regulator can stable the voltage level. Ceramic 10µF capacitos with SMD mounting form are easier to use for backfitting and have usually a lower ESR value.

Selection of the ATmega processor The using of the base function of the tester is still possible with a ATmega8. The flash memory of that device is used near 100%. Because the ATmega168 or ATmeg328 processors are pin-compatible to the ATmega8, I can recommend the replacement. Actually the price for ATmega328 is so cheap, that there is no reason to take a ATmega168 type. With a ATmega168/328 you get the following advantages: Self test with automatic calibration.
Improvement of measurement quality by automatic switching of ADC scale.
Measurement of inductors with resistance below 2100Ω.
Measurement of ESR value of capacitors with value of above 20nF.
The resolution of resistor measurement below 10Ω is 0.01Ω.
Using of pin PC4 as serial output.

Missing precision voltage reference Usually the software should detect the missing voltage reference with the unconnected pin PC4. In this case no VCC=x.xV message should appear in row 2 of the LCD on power on. If this message appear without the reference, you should connect a 2.2kΩ resistor to the PC4 input and VCC.

## 2.5 Chinese clones with text display

As I know, the tester is rebuild in China in two versions with character displays. The first model is rebuild from the first design of Markus F. without the ISP port. The assembled ATmega8 is placed in a socket, so you can replace it with a ATmega168 or ATmega328. For this version you should consider all the hints of section 2.4. Additional 100nF ceramic cpacitors should be connected near by the VCC-GND and AVCC-GND pins of the ATmega for better stabilization of the power voltage. Because there is no ISP connector at the board, you must expand the board with a ISP connector or you must plug the ATmega to a external socket for programming. In addition you should notice, that if your ATmega should run with a 8MHz crystal, your external ISP programmer must have a external clock for programming or a crystal mounted at the socket.

The second version of rebuilded tester is build with SMD components. Also the fix installed ATmega168 is a SMD type with 32TQFP body. Fortunately on the board is a 10-pole ISP connector provided for the programming. I have analysed the board version ”2.1 2012/11/06”. One error is the assembly of the part ”D1”, which should be a precision 2.5V voltage reference. Assembled is only a zener diode. This part should be removed. You can mount a LM4040AIZ2.5 or LT1004CZ-2.5 precision voltage reference at this place. A missing voltage reference is noticed by the software, so that you must not install the voltage reference. My exemplar was delivered with software version 1.02k. The 10-pole ISP plug was not assembled and I must install a jumper from ISP pin 6 to ISP pin
10. My programmer expect a GND connection at pin 10, but the board has GND level only on pin 4 and pin 6 of the ISP. The label of the ATmega168 was rub away and there was no documentation delivered with the part. The lock fuses of the ATmega were set, so no readout was possible. But I could install the software version 1.05k without any problems. Another user has problems with the same software version 1.05k. This user has the chinese board ”2.2 2012/11/26”. The software runs only without problems, if a additional 100nF keramic capacitor was placed between the pin

18-AVCC and 21-GND near by the ATmega. The software 1.05k uses the sleep state of the ATmega for waiting time. For this reason the current alternates often and the voltage regulator is stressed more. Further I have noticed, that the VCC voltage is blocked with a 100nF ceramic capacitor and with a 220µF electrolytic capacitor nearby the 78L05 voltage regulator. The 9V supply voltage is blocked with the same capacitors, but not at the input of the regulator but at the emitter of the PNP transistor (parallel with the battery). The printed circuit board track from the ATmega168 to the test port is very thin, so that a resistance of 100mΩ could be measured for one path. This will be the reason for measuring a resistance of 0.3Ω for two direct connected pins. The ESR measuring can usually consider this by zero compensation. Beginning with version 1.07k the software does respect this offset for measuring resistors below 10Ω too.

## 2.6 Chinese clones with graphical display

Newer rebuilds of the tester like a version from Fish8840 use a 128x64 pixel graphical display. This version use a modified circuit for the switch on logic. The figure 2.15 shows a part of the modified circuit.

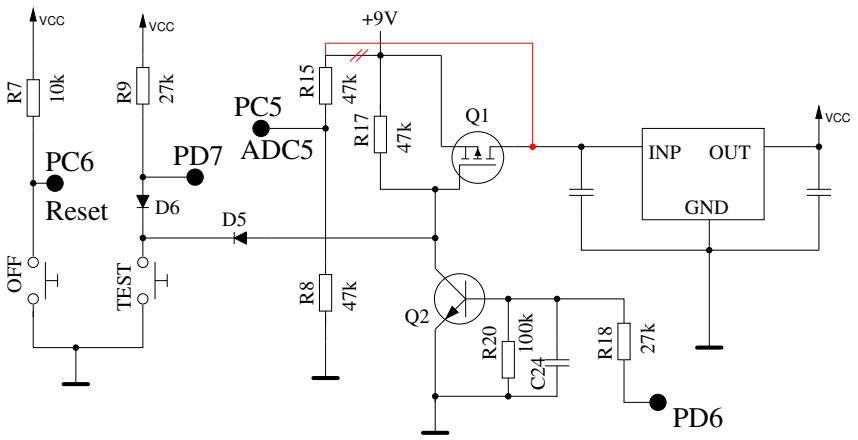
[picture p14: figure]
INP; OUT; GND; OFF; TEST; PD7 ADC5; Reset; VCC

Figure 2.15. Part of the circuit from the Fish8840 version

How you can see at the values of resistor R8 and R15, a 2:1 scaling factor for the battery voltage measurement is used instead of the original scaling factor. In addition R15 is direct connected to the battery, what results to a power consumption in the switch off state. The R15 should better be connected to the drain of Q1 or the input of the voltage regulator to prevent this unneeded battery power consumption. A suitable change of the printed board is shown in picture 2.16. A circuit path is cut between R17 and D5 and a new conductive path is inserted between Q1 and R15 with a enameled copper wire.

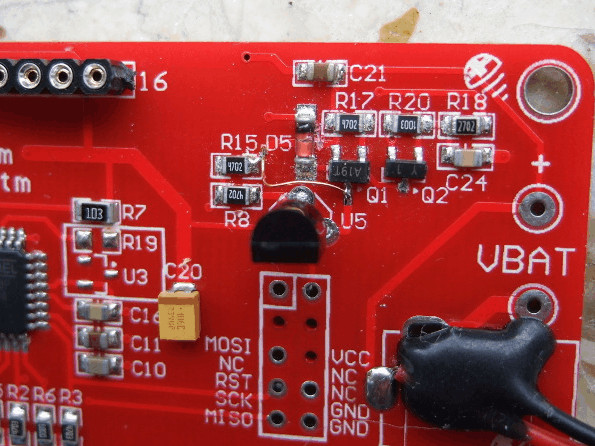
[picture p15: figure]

Figure 2.16. Picture of the changed Fish8840 printed board

The scaling factor of the battery voltage must be specified in any case in the Makefile before any attempt can be done to replace the original software (BAT NUMERATOR=66 for example).
The display module of the Fish8840 tester is equipped with a 3.3V voltage regulator to adapt the operating voltage of the display controller. Because the 3.3V operating voltage can be increased with the 5V signal level of the data signals from the ATmega, a adapter circuit according to the picture 2.17 is recommended. The four data signal lines are equipped with four serial 2.7kΩ resistors at a little breadboard. Longer spacer bolts must be used to mount the display with the adapter board to the printed board of the Fish8840 tester now.

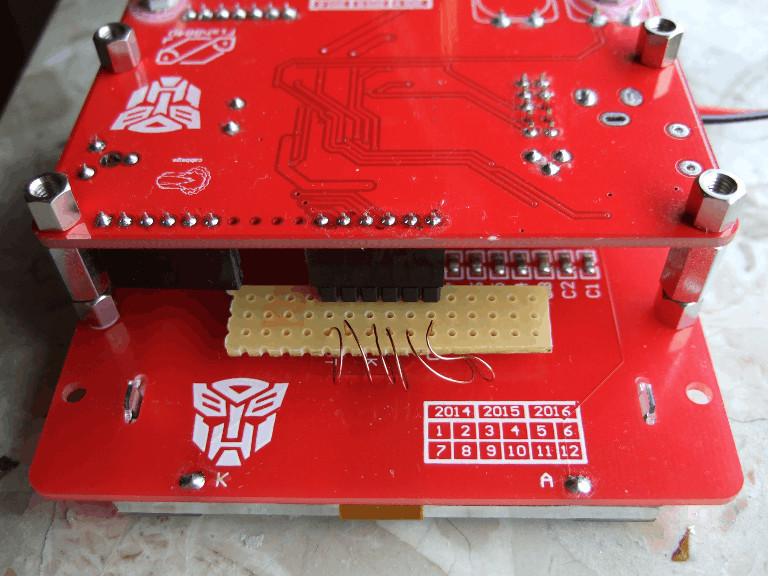
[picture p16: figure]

(a) Display with the breadboard adapter | (b) Ready mounted Tester

Figure 2.17. Adapter for a correctly display connection

Instead of this modification you can also use a special output mode of the 4 SPI signals of the ATmega with the Makefile option LCD SPI OPEN COL . With this option the outputs are not switched to VCC level, but the internal ”pull-up” resistors are switched on during the output of a high level. If the option PULLUP DISABLE is set, additionally a external pull-up resistor for the

”Reset” signal (PD0) is required. Because the data signals are never switched to VCC directly, the 3.3V power of the LCD controller can not be elevated. My version of the Fish8840 tester has all signals for connecting a character display routed to the LCD plug connector. Therefore you can prepare the board for connection of a character display, if the female header is completed and the potentiometer for the contrast level is added. However the supply pin 15 for the background light is connected directly to the VCC level. If you install a character display, you should check, that your display module is equipped with a serial resistor for the background LED. Of course iyou have to adapt the software for different displays. Also the hardware extension are possible with the Fish8840 board.

All attempt to replace the original software is allways done at one’s own risk. No guaranty can be given for operational capability of newer software versions. Unfortunately the original state of the chinese software can not be saved because the security bits of the ATmega328 are set. So there is no way to get back to the original state.

A additional version with graphical display is the WEI M8 printed board, which is shown in picture 2.18. This build use a LiIon accumulator with AA (mignon) size as power supply, which can be loaded with the micro USB plug. Operating is also possible without the accumulator, only with the USB power.

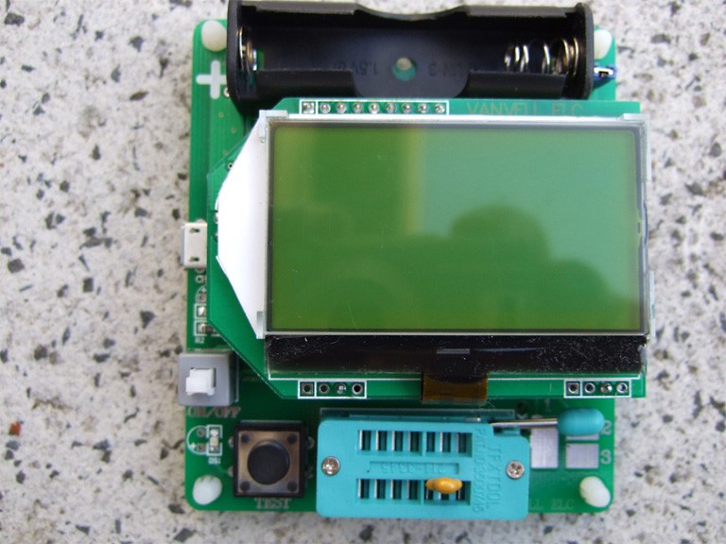
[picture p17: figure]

Figure 2.18. Picture of the chinese WEI M8 tester

It is pleasant, that the signal lines of the display are equipped with serial resistors at the adapter board, as you can see in the left picture of 2.19. Therefore you must not be afraid that the 5V signals of the ATmega can cause a excessive increase of the 3.3V power of the display controller.

(a) Adapter board for the display | (b) Base board

Figure 2.19. Inside look to the WEI M8 Testers

With the upgrade to version 1.12k some problems has occured. If the extended fuse is set to 0x04 (0xfc) as recommended, some measurements has caused a ”Brown Out” reset of the processor. This resets are caused by short voltage drops of the VCC power. I have added a additional 4.7µF ceramic capacitor at the input side of the voltage regulator and a 10µF ceramic capacitor at the output side (VCC) of the regulator. Both before and after the upgrade I have noticed, that with bipolar transistors a residual collector current (ICEO or ICEs) of about 1µA was detected with this board. Not until the unknown LDO voltage regulator was replaced with a MCP1702-5002 this effect has disappeared. The figure 2.20 shows the modified board with the slantwise mounted capacitors and the MCP1702 regulator. If you don’t wont to modify your board, you must set the extended fuse to 0x07 (0xff) to enable a regular operation. With that setting the voltage drops remain undetected.

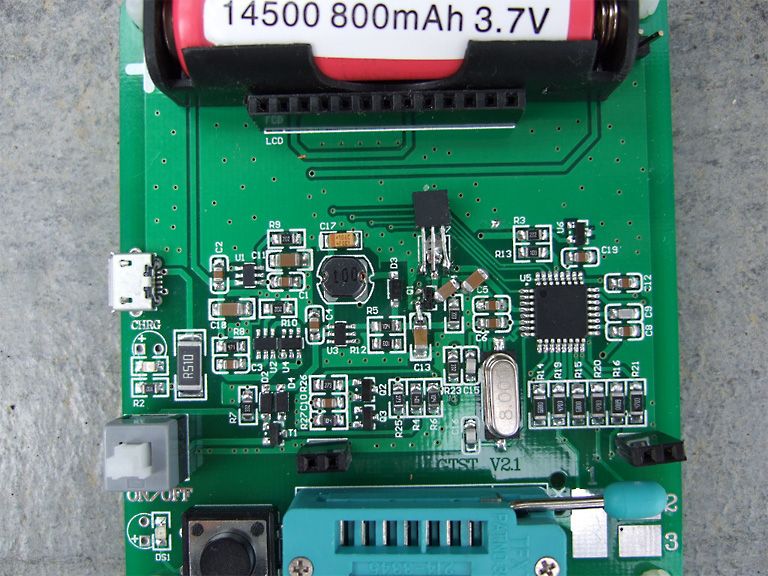
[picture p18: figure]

Figure 2.20. Picture of the modified WEI M8 Tester

A additional chinese version with graphical display is the ”LCD-T4” tester with a yellow printed board. I have removed the display for replacing the software with a newer version. At the right picture of figure 2.21 you can see in the right upper corner the ISP male connector with correct orientation beside the six holes of the board. For programming the ATmega I have not soldered the male connectorr. I have only pugged it into the holes instead and have fixed it with a finger during the programming. With that procedure the male connector can be easy removed an the display can be mounted again to it’s origin place. The chinese software could be replaced with the 1.12k without any noticeable problem. Also the activating of the ”brown-out” monitor by setting the extended fuse has not shown any surprice.

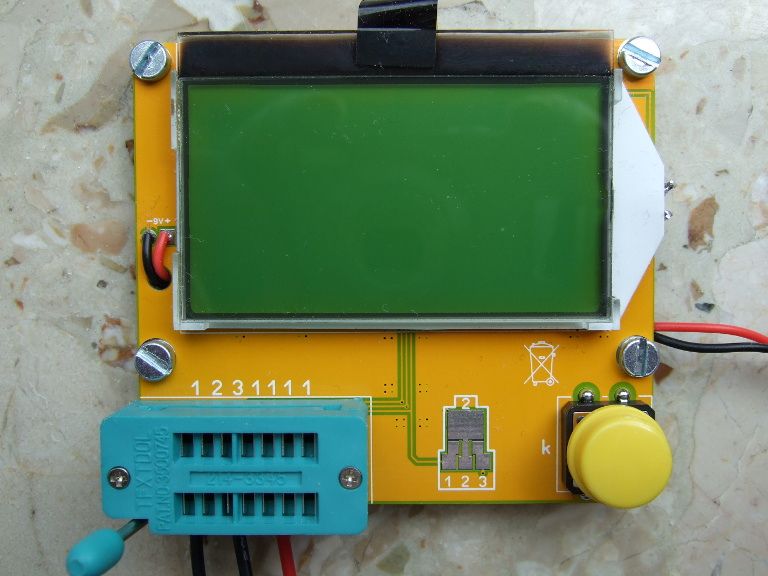
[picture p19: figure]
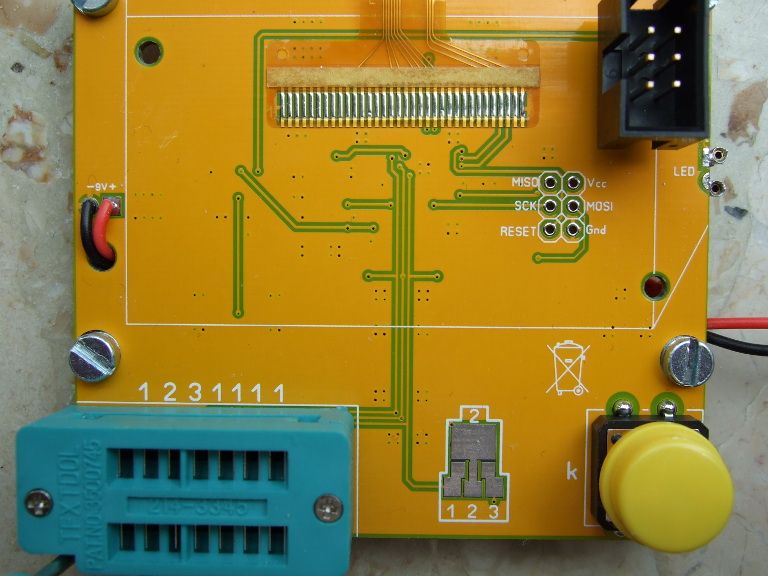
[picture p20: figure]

(a) completely | (b) with removed display

Figure 2.21. Front view of the T4 tester

You can see the upgraded 5mm threaded bolt and the upgraded cables with measurement clips at the pictures of the back side in figure 2.22. Because the data signals for the graphical LCD controller have also no level adaption (5V -> 3.3V ), the setting of the option LCD SPI OPEN COL is recommended. Due to the fact, that the board can not be easy upgraded with a ”pull-up” resistor, it make sense to remove the option PULLUP DISABLE instead. This board is lesser practical for later extensions, a replacement of the display is also difficult to realize.

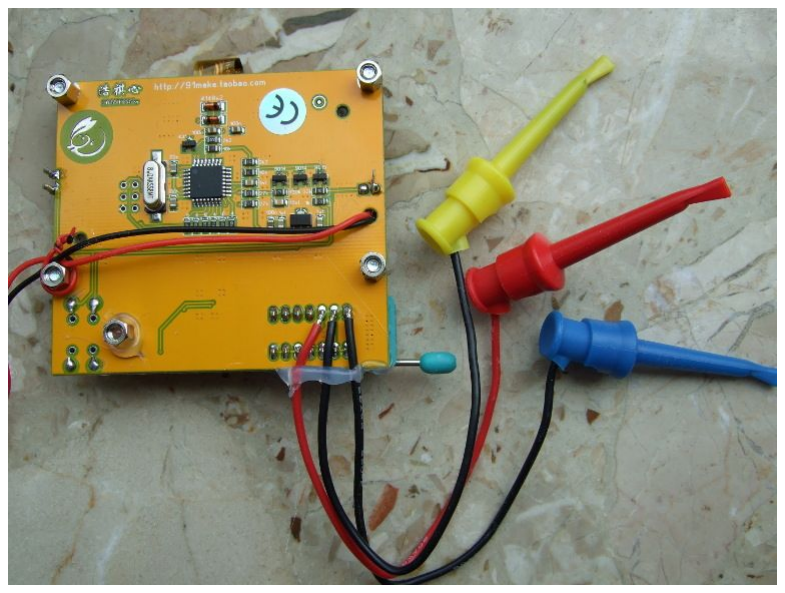
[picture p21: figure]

(a) components side | (b) with measurement cables

Figure 2.22. Back side of the T4 tester

A additional chinese version with graphical display is offered with the name ”GM328”. For this version the graphical display is connected with a adapter circuit board to the 16-pol female connector. The port PD5 of the ATmega is connected via pin 6 of the female connector to the CE (Chip Enable) input of the graphical controller. The signal CE is also conneted at the adapter board to the 0V power (GND). This will resulte to a short-circuit if the ATmega will switch the PD5 output to 5V . But newer versions of the software also switch the CE signal, even if the signal is not necessary for correct operation. For correct operation of the ”GM328” tester with newer software versions you should cut the connection of the CE signal to pin 6 of the male connector.

## 2.7 Chinese kits with graphic displays

Two different kit versions with graphical display and rotary encoder are known until now. The first released kit use a display with a ST7565 or compatible controller (128x64 pixels). In addition to the rotary encoder a additional input for frequency measurement is provided. For the test ports a 14-pin Textool socket, three soldering pads for cables and a testpad for SMD parts are provided at the main board. The pictures 2.23 shows the mounted kid. One of the both 22pF capacitors was replaced with a trimmer at the soldering side. With a trimmer the frequency of the crystal can be adjusted for better accuracy of frequency measurement and frequency generation.

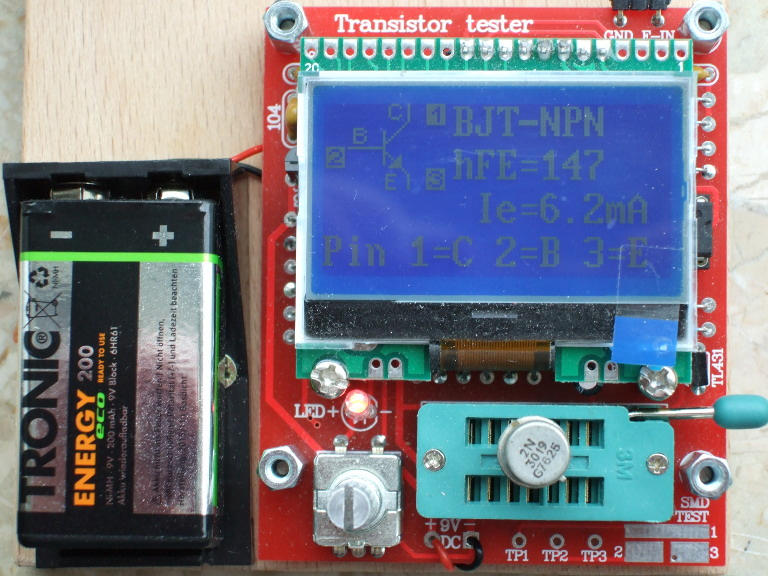
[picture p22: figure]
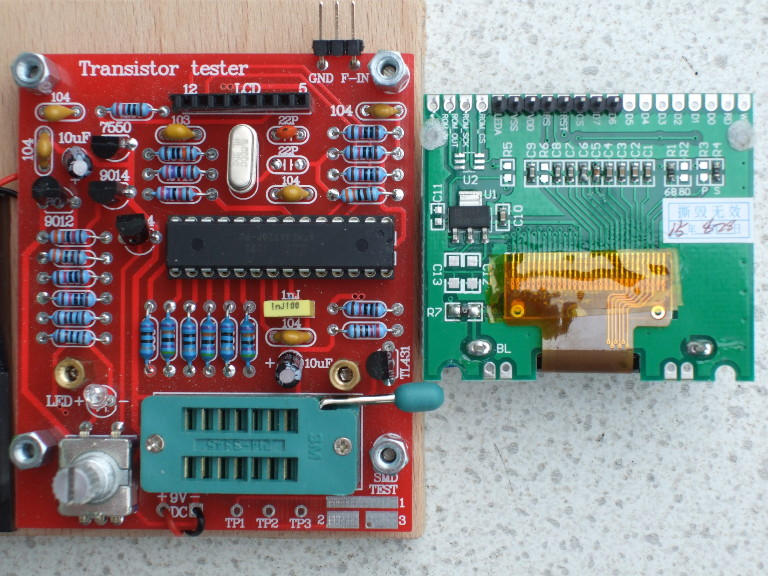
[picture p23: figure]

(a) build together | (b) with dismounted display

Figure 2.23. Assembled kit with 128x64 pixel display

The later released kit use a color display with a ST7735 controller (160x128 pixel) and is additionally equipped with a input for voltage measurement and a terminal for frequency output. But the frequency output terminal is not buffered, it is simply connected parallel to the TP2 terminal. The voltage measurement can handle positiv DC voltages up to 50V. A additional DC-DC converter for the measurement of Zener diodes is not provided. The pictures 2.24 shows this assembled kit. Also in this version was one of the both 22pF capacitors replaced by a trimmer (green color).

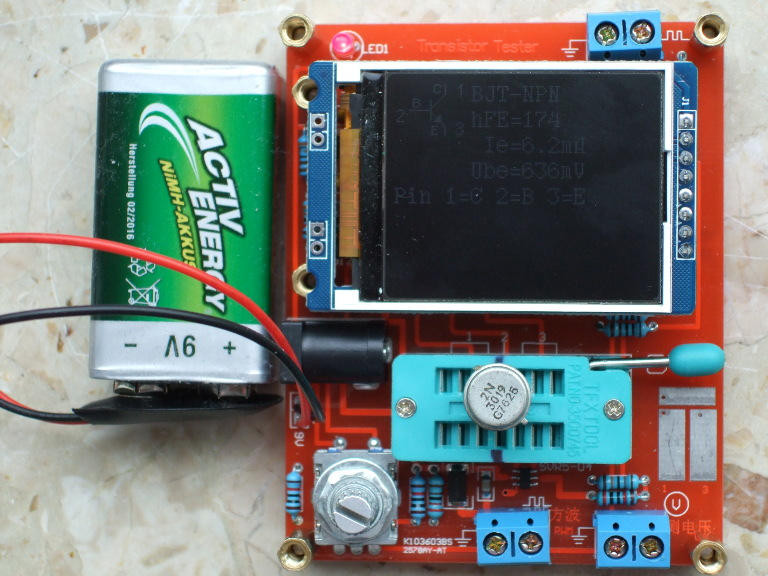
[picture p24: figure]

(a) build together | (b) with dismounted display

Figure 2.24. Assembled kit with 160x128 pixel color display

Both kids use a DIP version of the ATmega328P mounted at a sockets and are not equipped with a ISP connector for updating the ATmega with newer software versions. The first version use only leaded parts for the main circuit board. I have received measurement resistors 680Ω and 470kΩ with 0.1% tolerance with the Chinese kit. Also a 220nF capacitor for calibration was added to the kit. The kit with the color display was equipped with a connector for a DC power supply additionally to the pads for the 9V battery. Some few SMD parts was allready assembled at the main board, so that also only simple soldering tasks are to do for this kit. A little disadvantage of the version with the color display is the speed of display output. Especially for the menu handling the slower output speed will be noticed. Otherwise the color display has a significant higher count of pixels, so more text can be shown at once. Both kits use a 3.3V voltage regulator for the power of the display controller at the full assembled display circuit boards. Only the pin header must be soldered at the display circuit board. The color version use a CD4050 buffer to adapt the different signal voltage levels. I did not found any adaption of signal voltage levels at the board for the ST7565 version. Probably the selected controller version tolerates the 5V signal levels of the ATmega328. I could not find protection diodes at the input signals to the 3.3V supply side for this controller type.

## 2.8 Extented circuit with ATmega644 or ATmega1284

A extended circuit for ATmega644/1284 processors was developed with Nick L. from the Ukraine. The circuit 2.26 enables a additional test of crystals and a extended range for the frequency measurement. Although the basic circuit is very simular to the circuit 2.1, the port assignment is different. A rotary pulse encoder with circuit 2.6 can be connected here at the pins PB5 and PB7 (instead of PD1 and PD3). Both signals and also the power signals VCC and GND are available at the ISP connector, so that the extension can also be connected here.

The 16:1 frequency divider of the 74HC4060 is allways used for frequencies above 2MHz. The frequency divider can also be used for frequencies between 25kHz and 400kHz to upgrade the frequency resolution by using the period measurement. For switching between the operational states (frequency divider and crystal oszillator) the analog switches 74HC4052 are used. The table 2.8 shows the pin assignments for the ATmega324/644/1284 microcontrollers for different display connections. The using of the I²C interface is only possible with the SSD1306 controller. The signals of the I²C interface require a pull-up resistor of 4.7kΩ to 3.3V . The outputs of the ATmega is only switched to

0V for the I²C signals.

Port | Character LCD | Graphic LCD SPI 4-wire | Graphic LCD I 2C | additional function
PB2 | LCD-RS
PB3 | LCD-E | (LCD-CE) | LCD-SCL
PB4 | LCD-D4 | LCD-REST | LCD-SDA
PB5 | LCD-D5 | LCD-RS | | ISP-MOSI Rotary encoder 2
PB6 | LCD-D6 | LCD-SCLK | | ISP-MISO
PB7 | LCD-D7 | LCD-SI | | ISP-SCK Rotary encoder 1

Table 2.8. Different variations of the display port assignments

You can also connect a display with the NT7108 (KS0108, S6B0108) controller to the ATmega644 or ATmega1284 by using a little circuit as shown in figure 2.25. You should also respect the different pin assignments of display modules with NT7108 controllers as shown in table 2.5 at page 19.

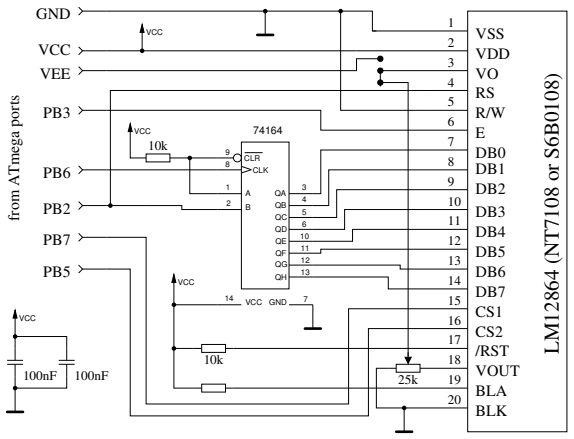
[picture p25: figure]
VSS VDD VO RS R/W E DB0 DB1 DB2; DB3 DB4 DB5 DB6 DB7 CS1 CS2 /RST VOUT BLA BLK; VCC; VEE; GND; from ATmega ports; CLR; CLK; 7 VCC

(a) with 74HCT164
(b) with 74HCT595

Figure 2.25. Connection of a NT7108 Controller to a ATmega644/1284

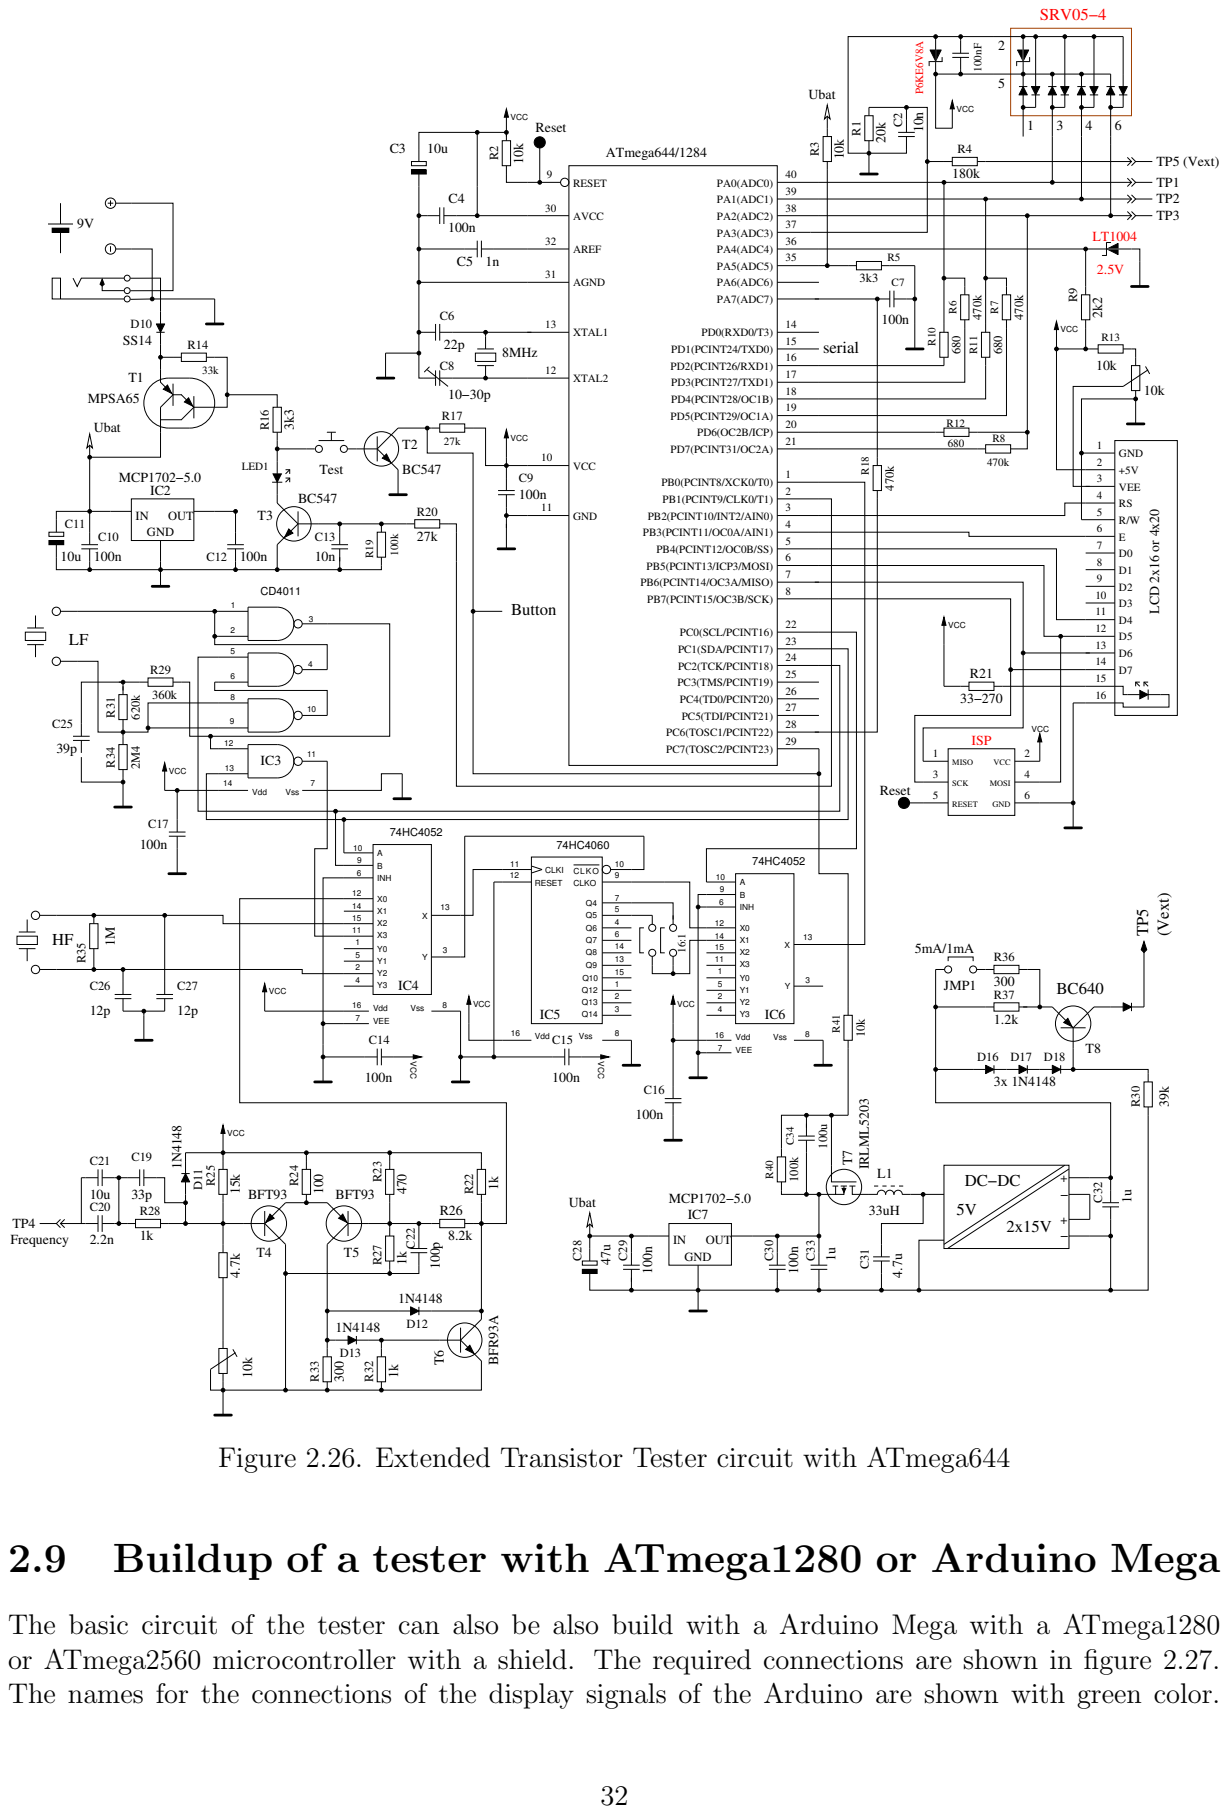
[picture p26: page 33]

Figure 2.26. Extended Transistor Tester circuit with ATmega644

2.9 Buildup of a tester with ATmega1280 or Arduino Mega

The basic circuit of the tester can also be also build with a Arduino Mega with a ATmega1280
or ATmega2560 microcontroller with a shield. The required connections are shown in figure 2.27.
The names for the connections of the display signals of the Arduino are shown with green color.

Components with red color identification are not required for operating. The ATmega2560 controller has many connectors, but only one connector has the required functions for both techniques of the frequency measurement. The connector must be used as clock input for a build in counter and must also be used as interrupt source for change of signal level. This feature is only available for the pin PE6 (T3/INT6). The other clock inputs of counters PD7 (T0), PD6 (T1), PH7 (T4) and PL2 (T5) can not be used as interrupt source for status change. Unfortunately the PE6 pin is not connected to a pin of the Arduino female connector strip. The PE5 pin (7) is connected to the connector 3 of the PWM socket strip and can be jumpered with the PE6 pin (8) of the ATmega2560. The output signal of the frequency generation is available at the PB6 (OC1B) pin. This pin is connected to the connector 12 of the PWM socket strip. The ISP-connector is not required, because the program can be loaded with the bootloader and the USB interface to the ATmega. With the bootloader there is always a little delay for the power up start of the program.

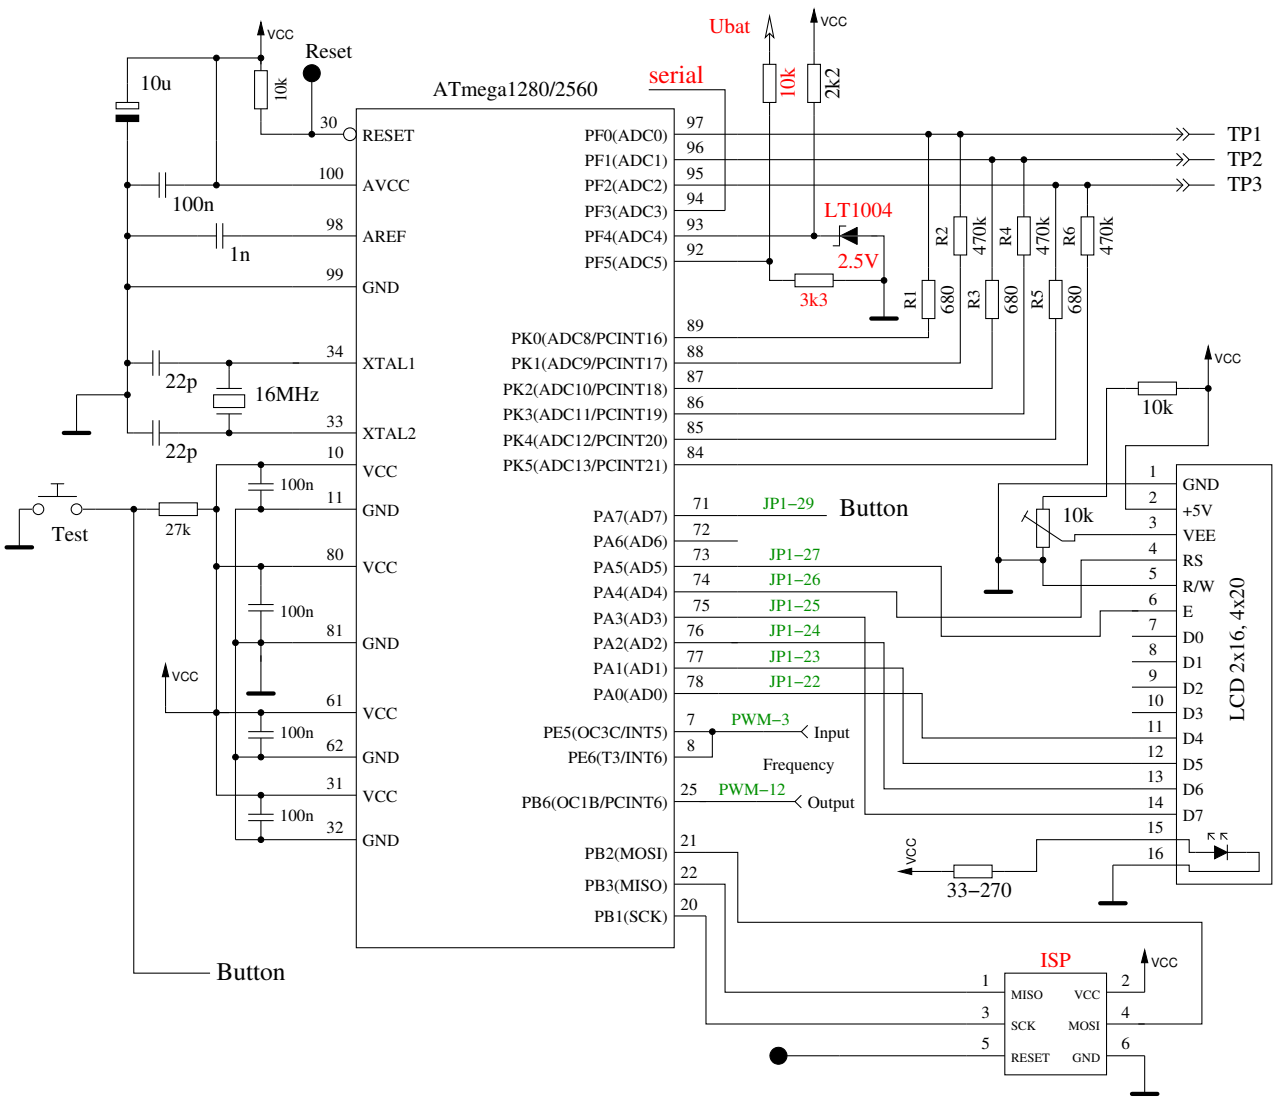
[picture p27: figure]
MISO; SCK; RESET; VCC; MOSI; GND; ISP; XTAL2; PK3(ADC11/PCINT19); PK2(ADC10/PCINT18); PK0(ADC8/PCINT16); PF1(ADC1); PF2(ADC2); PF3(ADC3); PF4(ADC4); PF5(ADC5); AREF; XTAL1; ATmega1280/2560; AVCC; 16MHz; LCD 2x16, 4x20; VEE; Ubat; Reset; serial; Test; PF0(ADC0); PK1(ADC9/PCINT17); PK4(ADC12/PCINT20); PK5(ADC13/PCINT21); PB1(SCK); PB3(MISO); PB2(MOSI); PE6(T3/INT6); PE5(OC3C/INT5); Button; Button JP1−29; PB6(OC1B/PCINT6); Frequency; Output; Input; PWM−3; PWM−12

Figure 2.27. TransistorTester circuit with ATmega1280, ATmega2560 or Arduino Mega

Of course you can connect all supported displays also to the ATmega1280 or ATmega2560 as shown in table 2.9 .

Port | Character LCD | ST7565 SPI | ST7920 seriell | NT7108 seriell | SSD1306 2C I | additional function
PA0 | LCD-D4 | LCD-REST | LCD-RESET | HC595-RCK
PA1 | LCD-D5 | LCD-RS | | LCD-CS2 | | rotary encoder 2
PA2 | LCD-D6 | LCD-SCLK | | HC164-CLK
PA3 | LCD-D7 | LCD-SI | | LCD-CS1 | | rotary encoder 1
PA4 | LCD-RS | | LCD-B0 | LCD-RS HC164-SER | LCD-SDA
PA5 | LCD-E | (LCD-CE) | LCD-EN | LCD-EN | LCD–SCL
PA7 | key signal

Table 2.9. Connections for different display to the ATmega1280/2560 processors

## 2.10 Programming of the microcontroller

I release the software for the microcontroller with source code. The developement is done with Linux operationg system (Ubuntu) and is controlled with a Makefile. The Makefile makes sure, that your software will be compiled with the prior selected Makefile options. Some constellations are precom-piled with the source. Please take a look to the ReadMe.txt file in the directory Software/default and to the chapter 4 at page 48. The result of compilation have the extensions .hex and .eep . Usually the names will be TransistorTester.hex and TransistorTester.eep . The .hex file contains the data for the program memory (flash) of the ATmega processor. The .eep file contains the data for the EEprom memory of the ATmega. Both data files must be loaded to the correct memory. Additionally the operating state of the ATmega processor must be programmed with the “fuses”. If you can use my Makefile and additionally the program avrdude [12], you need no exact knowledge of the details about the fuses. You have only to type “make fuses” if you have no crystal or “make fuses-crystal” if you have installed the 8MHz crystal to your printed board. With the ATmega168 series of the microcontroller you can also use “make fuses-crystal-lp” to use a crytal with the low power mode. Never choose the crystal mode of clock generation, if you don’t have installed the 8MHz crystal. If you are not sure with the fuses, leave them as default set by manufactor and first bring the the tester to operation in this mode. Maybe your program runs too slow, if you use program data compiled for 8MHz operation, but you can correct this later! But a wrong set of fuses may inhibit later ISP-programming.

### 2.10.1 Using the Makefile with Linux

You can install packages with Debian based Linux versions by using a package manager as synaptic or dpkg. The package “subversion” must be installed for downloading the sources or the documentation from the SVN archive. With the command
“svn checkout svn://www.mikrocontroller.net/transistortester”
you can download the complete archive. Of course you can also download only subdirectories of the archive. For using the Makefile in one of the subdirectories you must install the packages make, binutils-avr, avrdude, avr-libc and gcc-avr. Once you must prepare the access to the interfaces for the user. If you open a consol window and you have also connected a ISP programmer with USB interface, you can see the recognized USB devices with the command ”lsusb”. A sample of the result of lsusb you can see here:

Bus 001 Device 001: ID 1d6b:0002 Linux Foundation 2.0 root hub
Bus 002 Device 003: ID 046d:c050 Logitech, Inc. RX 250 Optical Mouse

Bus 002 Device 058: ID 03eb:2104 Atmel Corp. AVR ISP mkII
Bus 002 Device 059: ID 2341:0042 Arduino SA Mega 2560 R3 (CDC ACM)
Bus 002 Device 001: ID 1d6b:0001 Linux Foundation 1.1 root hub

A Device 58 is detected here a a AVR ISP mkII type (DIAMEX ALL-AVR). The ID 03eb is a vendor ID and the ID 2104 is a product ID. Both ID’s are required for a entry in the file /etc/udev/rules.d/90-atmel.rules . In this example the file 90-atmel.rules has one line:

SUBSYSTEM=="usb", ATTRS{idVendor}=="03eb", ATTRS{idProduct}=="2104", MODE="0660", GROUP="plugdev"

This entry allow the access to the USB device 58 for members of the group ”plugdev”. The also detected USB device 59 allows a access to the serial device ”/dev/ttyACM0” for members of the group ”dialout”.
Therefore your user identification should be a member of the group plugdev and also a member of the group dialout. With the command ”usermod -a -G dialout,plugdev $USER” the membership of both groups should be established. Now the program avrdude should have permission to access both devices. In a console window you must first change the directory with the command “cd” to a proper subdirectory of the directory trunk. Now you can change options of the Makefile with any text editor. For compiling the source you must only type the simple command “make”. If the ISP programmer is configured proper in the Makefile, a command “make upload” should result to load the program with the ISP interface to the ATmega. The “fuses” of the ATmega must also be set correctly once. You can achieve this with the command “make fuses” or “make fuses-crystal”. The program avrdude probably reports a error for setting the extended fuse efuse. The reading of unused fuse bits is specified as ”1” for the ATmega, but the avrdude program mask the unused bits, so that it expect a ”0” for all unused bits. Normally the efuse should be set to 0xfc, but avrdude read back 0x04 with the mask. You can change the file avrdude.conf to change the behaviour of avrdude or you can set the efuse to 0x04. The value for all efuses can be set with the identifier EFUSE VAL at the begin of file setup.mk in the trunk directory. Probably the fuses are also set correctly with the error message.

### 2.10.2 Using the WinAVR package with Windows

If you use the Windows operating system, the easiest way to get a correct programmed ATmega is to use the WinAVR package [16],[17]. With my patch [18] you can also set the fuses by using the Makefile. Of course the avrdude program must support your programmer and the configuration in the Makefile must match to your environment.
The figures 2.28 show the File menu of the graphical user interface of WinAVR for open the file Makefile and for saving the changed Makefile (Save).

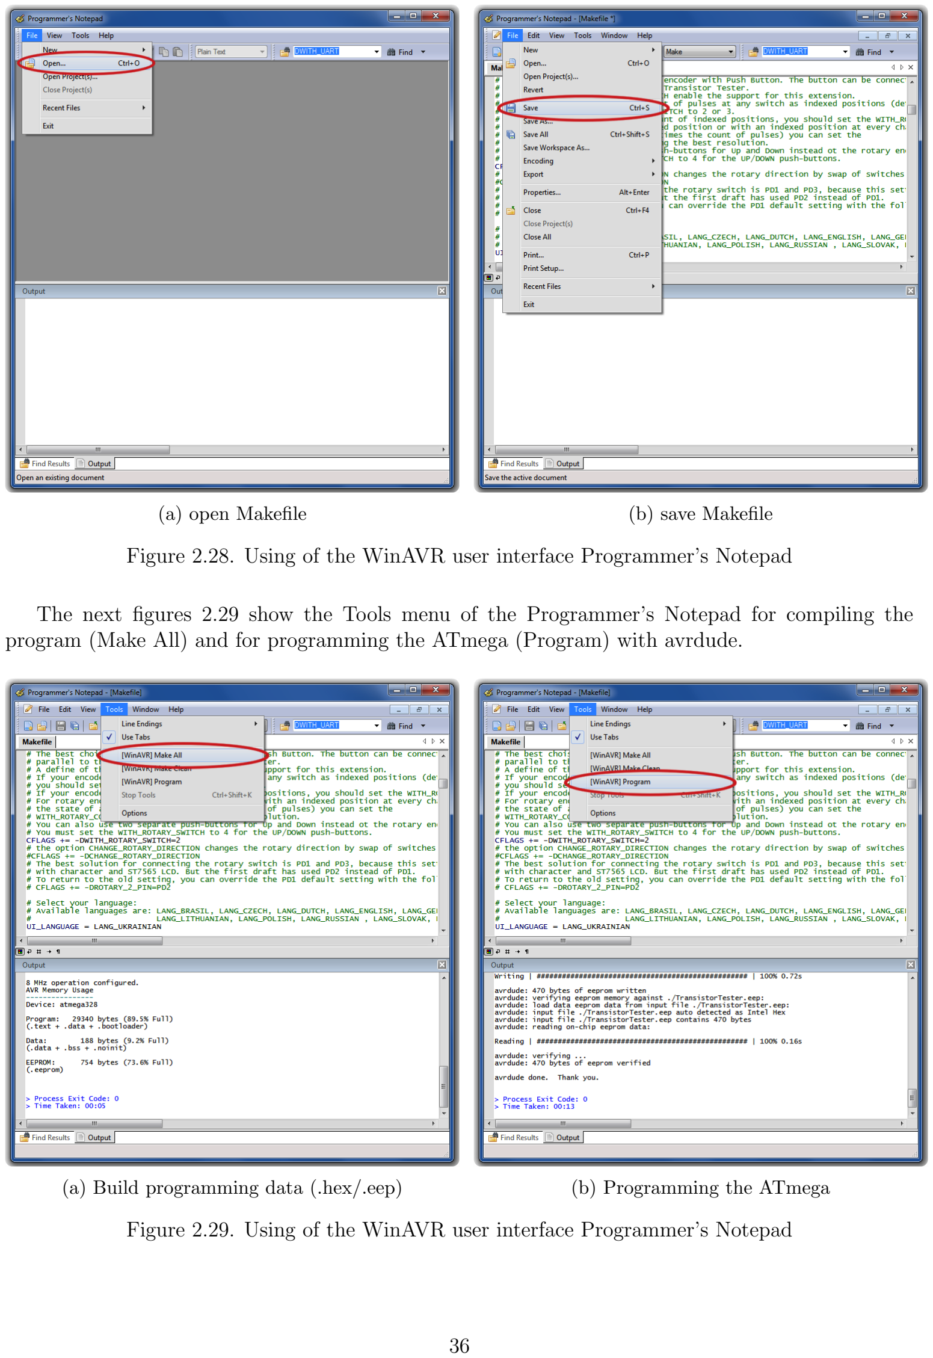
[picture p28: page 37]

(a) open Makefile | (b) save Makefile

Figure 2.28. Using of the WinAVR user interface Programmer’s Notepad

The next figures 2.29 show the Tools menu of the Programmer’s Notepad for compiling the program (Make All) and for programming the ATmega (Program) with avrdude.

(a) Build programming data (.hex/.eep) | (b) Programming the ATmega

Figure 2.29. Using of the WinAVR user interface Programmer’s Notepad

## 2.11 Troubleshooting

In most cases of problems you will miss the text output to the LCD-display. At first you should check, if the LED was illuminated weak, if you release the Test button.

Power does not switch on. If the LED is without light and the VCC power has correct 5V voltage during holding the Test button, the microcontroller does not switch the power correctly. The microcontroller should hold the power by switching the PD6 output to 5V , which is usually done as one of the first actions. If you hold the Test key pressed, the power is switched on anyway. So you can check the value of VCC power and additionally the voltage value of the PD6 output, if you hold the key pressed. If VCC voltage has correct value (5V ), but PD6 voltage is below 4V , your microcontroller does not start the program. In this case you should check if the microcontroller flash has been loaded with proper data for your installed type and if ATmega is correctly configured with the fuses. If your ATmega put the PD6 output to 5V and the power does not stay if you release the Test key, it is more difficult to find the reason. First you can shorten the LED and try again. If your Tester now starts, your LED may be faulty or mounted with wrong polarity. If this is not the reason, the current amplification factor of your T3 transistor (BC557C) is insufficient. The current to the base of T3 is lower in the microcontroller state as in the “key pressed” state.

Nothing is readable on the LCD display Check the voltage at the contrast pin at the LCD display (pin 3). Adjust to correct value specified in the data sheet of your display and optimize by viewing. If you have a high temperature display type, you must provide a negative contrast voltage for operation. In this case you can use the ICL 7660 device for generating a negative voltage from positive 5V .

The tester software can be configured for many different controller with different connection types. You should check, if your software matches to your mounted display type. If there is no output readable on the LCD and the background light is on, you should disconnect the power and check all four data plus the two control signal connections. If all connection are well, the only reason I see is a uncorrect timing of control signals. This can be caused by a slower LCD controller than expected by the software or the ATmega software runs at wrong clock speed. Please check for which clock speed your programming data was compiled and if the fuses of the ATmega are correct set to that speed. You find the clock parameter in the corresponding Makefile. If the tester is build without the switch off electronic, you can test with a LED connected to the test pins, if the program operates normally. If the LED flickers, the program operates well. The missing text on the LCD must be caused by wrong connection or timing. For some graphical displays the contrast is changeable with a menu function. If you have changed the contrast value, that nothing is readable at the screen, you cannot handle the menu function any more. You can try to read the display from a slanting look to the display, not from the front side. In this case you can try to handle the menu function with this view. Otherwise you can write the EEprom data new with a ISP programmer to reset the contrast value.

Something but not all is readable on the LCD display Check if the .eep data are loaded to the EEprom memory of ATmega. If all data are loaded correctly, you should check the clock speed of your programming data (Makefile) and ATmega processor settings (fuses).

Measurement is slow and Capacitors are measured about 8 times too small You run software compiled for 8MHz clock at real clock speed of 1MHz. Please set the fuses of the ATmega correctly.

Measurement has strangely values Check if your programmer is still connected to the ISP-plug. The ISP interface should be disconnected for measuring. Very often the reason of wrong measurements is the use of software compiled with the AUTOSCALE ADC option and with the option NO REF CAP, but the capacitor at the AREF pin has still a value of 100nF. Wrong assembly of components or remaining soft solder flux can disturb the measurements too. Please check with the selftest function of your TransistorTester software if possible. For the details see Chapter 5.5.

Otherwise inspect your board visually and check the resistor values with a ohmmeter. You can use the pins of the ATmega for this check, for example to check the R1 you can measure between pin 23 and pin 14. Take a look at the circuit diagram 2.1 for details. There is no need to remove the microcontroller, only battery or power supply should be removed before.

The Tester switch off the power after 2 seconds display time This condition exists, if the external Pull-Up resistor at the PD7 input is missing or the key button is keep pressed. The software switch off the internal Pull-Up resistors to prevent a influence to the measurement results. Therefore a external Pull-Up resistor (27k) is required.

Der Tester shows only Vext=xx.xV in row 2 This problem exists, if the Pull-Up resistor at the PD7 input is missing or the key button is keep pressed. Additionally the software is configured without the serial output (without option WITH UART) and without the internal Pull-Up resistors (with option PULLUP DISABLE). You should install the Pull-Up resistor at pin PD7.

# Chapter 3

# Instructions for use

## 3.1 The measurement operation

Using of the Transistor-Tester is simple. Anyway some hints are required. In most cases are wires with alligator clips connected to the test ports with plugs. Also sockets for transistors can be connected. In either case you can connect parts with three pins to the three test ports in any order. If your part has only two pins, you can connect this pins to any two of the tree test ports. Normally the polarity of part is irrelevant, you can also connect pins of electrolytical capacitors in any order. The measurement of capacity is normally done in a way, that the minus pole is at the test port with the lower number. But, because the measurment voltage is only between 0.3V and at most 1.3V , the polarity doesn´t matter. When the part is connected, you should not touch it during the measurement. You should put it down to a nonconducting pad if it is not placed in a socket. You should also not touch to the isolation of wires connected with the test ports. Otherwise the measurement results can be affected. Then you should press the start button. After displaying a start message, the measurement result should appear after two seconds. If capacitors are measured, the time to result can be longer corresponding to the capacity.
How the transistor-tester continues, depends on the configuration of the software.
Single measurement mode If the tester is configured for single measurement mode (POWER OFF option), the tester shut off automatical after displaying the result for 28 seconds for a longer lifetime of battery. During the display time a next measurement can be started by pressing the start button. After the shut off a next measurement can be started too of course. The next measurement can be done with the same or another part. If you have not installed the electronic for automatic shut down, your last measurement result will be displayed until you start the next measurement.

Endless measurement mode A special case is the configuration without automatical shut off. For this case the POWER OFF option is not set in the Makefile. This configuration is normally only used without the transistors for the shut off function. A external off switch is necessary for this case. The tester will repeat measurements until power is switched off.

Multi measurement mode In this mode the tester will shut down not after the first measurement but after a configurable series of measurements. For this condition a number (e.g. 5) is assigned to the POWER OFF option. In the standard case the tester will shut down after five measurements without found part. If any part is identified by test, the tester is shut down after double of five (ten) measurements. A single measurement with unknown part after a series of measurement of known parts will reset the counter of known measuerements to zero. Also a single measurement of known part will reset the counter of unknown measurements to zero. This behavior can result in a nearly endless series of measurements without pressing the start button, if parts are disconnected and connected in periodical manner.

In this mode there is a special feature for the display period. If the start button is pressed only short for switching on the tester, the result of measurement ist only shown for 5 seconds. Buf if you press and hold the start button until the first message is shown, the further measurement results are shown for 28 seconds. The next measurement can started earlier by pressing the start button during the displaying of result.

## 3.2 Optional menu functions for the ATmega328

If the menu function is selected, the tester start a selection menu after a long key press (> 500ms) for additional functions. This function is also available for other processors with at least 32K flash memory. The selectable functions are shown in row two of a 2-line display or as marked function in row 3 of a 4-line display. The previous and next function is also shown in row 2 and 4 of the display in this case. After a longer wait time without any interaction the program leave the menu and returns to the normal transistor tester function. With a short key press the next selection can be shown. A longer key press starts the shown or marked function. After showing the last function ”switch off”, the first function will be shown next.
If your tester has also the rotary pulse encoder installed, you can call the menu with the additional functions also with a fast rotation of the encoder during the result of a previous test is shown. The menu functions can be selected with slow rotation of the encoder in every direction. Starting of the selected menu function can only be done with a key press. Within a selected function parameters can be selected with slow rotation of the encoder. A fast rotarion of the encoder will return to the selection menu.

frequency The additional function ”frequency” (frequency measurement) uses the ATmega Pin PD4, which is also connected to the LCD. First the frequency is allways measured by counting. If the measured frequency is below 25kHz, additionally the mean period of the input signal is measured and with this value the frequency is computed with a resolution of up to 0.001Hz. By selecting the POWER OFF option in the Makefile, the period of frequency measurement is limited to 8 minutes. The frequency measurement will be finished with a key press and the selectable functions are shown again.

f-Generator With the additional function ”f-Generator” (frequency generator) you can select output frequencies between 1Hz and 2MHz. You can change the selected frequency only at the highest shown digit location. For the locations 1Hz up to 10kHz digits between 0 and 9 can be selected. For the highest 100kHz location you can select numericals between 0 and 20. In row 1 of the frequency line is indicated with the symbol > or < , if a longer key press (> 0.8s) select a higher or lower digit location. You can only select a lower location (<), if the current location has selected the 0 digit and if the current location is not the lowest with 1Hz steps. If you have selected the 100kHz location, the > symbol is replaced by a R character. A longer key press (> 0.8s) will result a reset of the frequency value to the initial value of 1Hz in this case. If the POWER OFF option is selected in the Makefile, the key must be pressed longer, because a short key press (< 0.2s) only reset the time limit of 4 minutes. The elapsed time is shown with a point for every 30 seconds in row 1 of the display. With periodical short key press you can prevent the time out of the frequency generation. With a long key press (> 2s) you will stop the frequency generator and return to the function menu.

10-bit PWM The additional function ”10-bit PWM” (Pulse Width Modulation) generates a fixed frequency with selectable puls width at the pin TP2. With a short key press (< 0.5s) the pulse width is increased by 1%, with a longer key press the pulse width is increased by 10%. If 99% is overstepped, 100% is subtracted from the result. If the POWER OFF option is selected in the Makefile, the frequency generation is finished after 8 minutes without any key press. The frequency generation can also be finished with a very long key press (> 1.3s).

C+ESR@TP1:3 The additional function ”C+ESR@TP1:3” selects a stand-alone capacity measurement with ESR (Equivalent Series Resistance) measurement at the test pins TP1 and TP3. Capacities from 2µF up to 50mF can be measured. Because the measurement voltage is only about 300mV , in most cases the capacitor can be measured ”in circuit” without previous disassembling. If the POWER OFF option is selected in the Makefile, the count of measurements is limited to 250, but can be started immediately again. The series of measurements can be finished with a long key press.

Resistor meter With the 1 3 symbol the tester changes to a resistor meter at TP1 and TP3 . This operation mode will be marked with a [R] at the right side of the first display line. Because the ESR measurement is not used in this operation mode, the resolution of the measurement result for resistors below 10Ω is only 0.1Ω. If the resistor measurement function is configured
with the additional inductance measurement, a 1 | 3 symbol is shown at this menu.
Then the resistor meter function includes the measurement of inductance for resistors below 2100Ω. At the right side of the first display line a [RL] is shown. For resistors below 10Ω the ESR measurement is used, if no inductance is find out. For this reason the resolution for resistors below 10Ω is increased to 0.01Ω. With this operation mode the measurement is repeated without any key press. With a key press the tester finish this operation mode and returns to the menu. The same resistor meter function is started automatically, if a single resistor is connected between TP1 and TP3 and the start key was pressed in the normal tester function. In this case the tester returns from the special mode opration to the normal tester function with a key press.

Capacitor meter With the 1 3 symbol the tester changes to a capacitor meter function at TP1 and TP3. This operation mode will be marked with a [C] at the right side of the first display line. With this operation mode capacitors from 1pF up to 100mF can be measured. In this operation mode the measurement is repeated without key press. With a key press the tester finish this operation mode and returns to the menu. In the same way as with resistors, the tester changes automatically to the capacitor meter function, if a capacitor between TP1 and TP3 is measured with the normal tester function. After a automatically start of the capacitor meter function the tester returns with a key press to the normal tester function.

rotary encoder With the function ”rotary encoder” a rotary encoder can be checked. The three pins of the rotary encoder must be connected in any order to the three probes of the transistor tester before the start of the function. After starting the function the rotary knob must be turned not too fast. If the test is finished successfully, the connection of the encoder switches is shown symbolic in display row 2. The tester finds out the common contact of the two switches and shows, if the indexed position has both contacts in open state (’o’) or in closed state (’C’). A rotary encoder with open switches at the indexed positions is shows in row 2 for two seconds as ”1-/-2-/-3 o”. This type of encoder has the same count of indexed positions as count of pulses for every turn. Of course the pin number of the right common contact is shown in the middle instead of ’2’. If also the closed switches state is detected at the indexed positions, the row 2 of the display is also shown as ”1—2—3 C” for two seconds. I don’t know any rotary encoder, which have the switches always closed at any indexed position. The interim state of the switches between the indexed positions is also shown in row 2 for a short time (< 0.5s)

without the characters ’o’ or ’C’. If you will use the rotary encoder for handling the tester, you should set the Makefile option WITH ROTARY SWITCH=2 for encoders with only the open state (’o’) and set the option WITH ROTARY SWITCH=1 for encoders with the open (’o’) and closed (’C’) state at the indexed positions.

C(µF)-correction With this menu function you can change a correction factor for bigger capacity values. You can preset the same factor with the Makefile option C H KORR. Values above zero reduce the output value of the capacity with this percent value, values below zero will increase the shown capacity value. A short key press will reduce the correction value about 0.1%, a longer key press will increase the correction value. A very long key press will save the correction value. It is a characteristic of the used measurement method, that capacitors with low quality like electrolytic type will result to a too high capacity value. You can detect a capacitor with low quality by a higher value of the Vloss parameter. High quality capacitors have no Vloss or only 0.1%. For adjusting this parameter you should only use capacitors with high quality and a capacity value above 50µF. By the way the exactly capacity value of electrolytic capacitors is unimportant, because the capacity value differ with temperature and DC-voltage.

Selftest With the menu function ”Selftest” a full selftest with calibration is done. With that call all the test functions T1 to T7 (if not inhibited with the NO TEST T1 T7 option) and also the calibration with external capacitor is done every time.

Voltage The additional function ”Voltage” (Voltage measurement) is only possible, if the serial output is deselected or the ATmega has at least 32 pins (PLCC) and one of the additional pins ADC6 or ADC7 is used for the measurement. Because a 10:1 voltage divides is connected to PC3 (or ADC6/7), the maximum external voltage can be 50V . A installed DC-DC converter for zener diode measurement can be switched on by pressing the key. Thus connected zener diodes can be measured also. By selecting the POWER OFF option in the Makefile and without key pressing, the period of voltage measurement is limited to 4 minutes. The measurement can also be finished with a extra long key press (> 4 seconds).

Contrast This function is available for display controllers, which can adjust the contrast level with software. The value can be decreased by a very short key press or left turn with the rotary encoder. A longer key press (> 0.4s) or a right turn of the rotary encoder will increase the value. The function will be finished and the selected value will be saved nonvolatile in the
EEprom memory by a very long key press (> 1.3s).

BackColor For color displays this menu item can be enabled with the Makefile option LCD CHANGE COLOR for selecting the background color. The rotary encoder extension must be installed. You can
select the colors red, green and blue with a longer key press. The intensity value of the selected
color, which is marked with a ¿ symbol in column 1, can be changed by a turn of the rotary
encoder.

FrontColor For color displays this menu item can be enabled with the Makefile option LCD CHANGE COLOR for selecting the foreground color. The rotary encoder extension must be installed. You can
select the colors red, green and blue with a longer key press. The intensity value of the selected
color, which is marked with a ¿ symbol in column 1, can be changed by a turn of the rotary
encoder.

Show data The function ,,Show Data” shows besides the version number of the software the data of the calibration. These are the zero resistance (R0) of the pin combination 1:3, 2:3 and 1:2 . In addition the resistance of the port outputs to the 5V side (RiHi) and to the 0V side (RiLo) are shown. The zero capacity values (C0) are also shown with all pin combinations (1:3, 2:3, 1:2 and 3:1, 3:2 2:1). Next the correction values for the comparator (REF C) and for the reference voltage (REF R) are also shown. With graphical displays the used icons for parts and the font set is also shown. Every page is shown for 15 seconds, but you can select the next page by a key press or a right turn of the rotary encoder. With a left turn of the rotary encoder you can repeat the output of the last page or return to the previous page.

Switch off With the additional function ”Switch off” the tester can be switched off immediately.

Transistor Of course you can also select the function ”Transistor” (Transistor tester) to return to a normal Transistor tester measurement.

With the selected POWER OFF option in the Makefile, all additional functions are limited in time without interaction to prevent a discharged battery.

## 3.3 Selftest and Calibration

If the software is configured with the selftest function, the selftest can be prepared by connecting all three test ports together and pushing of the start button. To begin the self test, the start butten must be pressed again within 2 seconds, or else the tester will continue with a normal measurement. If the self test is started, all of the documented tests in the Selftest chapter 5.5 will be done. If the tester is configured with the menu function (option WITH MENU), the full selftest with the tests T1 to T7 are only done with the ”Selftest” function, which is selectable as menu function. In addition the calibration with the external capacitor is done with every call from function menu, otherwise this part of calibration is only done first time. Thus the calibration with the automatically started selftest (shorted probes) can be done faster. The repetition of the tests T1 to T7 can be avoided, if the start button is hold pressed. So you can skip uninteresting tests fast and you can watch interresting tests by releasing the start button. The test 4 will finish only automatically if you separate the test ports (release connection).
If the function AUTO CAL is selected in the Makefile, the zero offset for the capacity measurement will be calibrated with the selftest. It is important for the calibration task, that the connection between the three test ports is relased during test number 4. You should not touch to any of the test ports or connected cables when calibration (after test 6) is done. But the equipment should be the same, which is used for further measurements. Otherwise the zero offset for capacity measurement is not detected correctly. The resistance values of port outputs are determined at the beginning of every measurement with this option.

If you have selected the samplingADC function in the Makefile with the option ”WITH SamplingADC = 1”, two special steps are included to the calibration precedure. After the normal measuring of the zero capacity values, also the zero capacity values for the samplingADC function is measured (C0samp). As last step of the calibration the connection of a test capacitor at pin 1 and pin 3 is requested for later measurement of little coils with the message 1 3 10-30nF[L]. The capacity value should be between 10nF and 30nF, to get a measurable resonant frequency by later parallel connection to a coil with less than 2mH. For inspection of coils with more than 2mH inductance the normal measurement method should result to a sufficient accuracy. The parallel connection of the capacitor to use the other measurement method should not be usefull.

A capacitor with any capacity between 100nF and 20µF connected to pin 1 and pin 3 is required after the measurement of the zero capacity values. To indicate that, the message 1 3 >100nF is shown in row 1 of the display. You should connect the capacitor not before the message C0= or this text is shown. With this capacitor the offset voltage of the analog comparator will be compensated for better measurement of capacity values. Additionally the gain for ADC measurements using the internal reference voltage will be adjusted too with the same capacitor for better resistor measurement results with the AUTOSCALE ADC option. If the menu option is selected for the tester and the selftest is not started as menu function, the calibration with the external capacitor is only done for the first time calibration. The calibration with the external capacitor can be repeated with a selftest call as menu selection.
The zero offset for the ESR measurement will be preset with the option ESR ZERO in the Makefile. With every self test the ESR zero values for all three pin combinations are determined. The solution for the ESR measurement is also used to get the values of resistors below 10Ω with a resolution of 0.01Ω.
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

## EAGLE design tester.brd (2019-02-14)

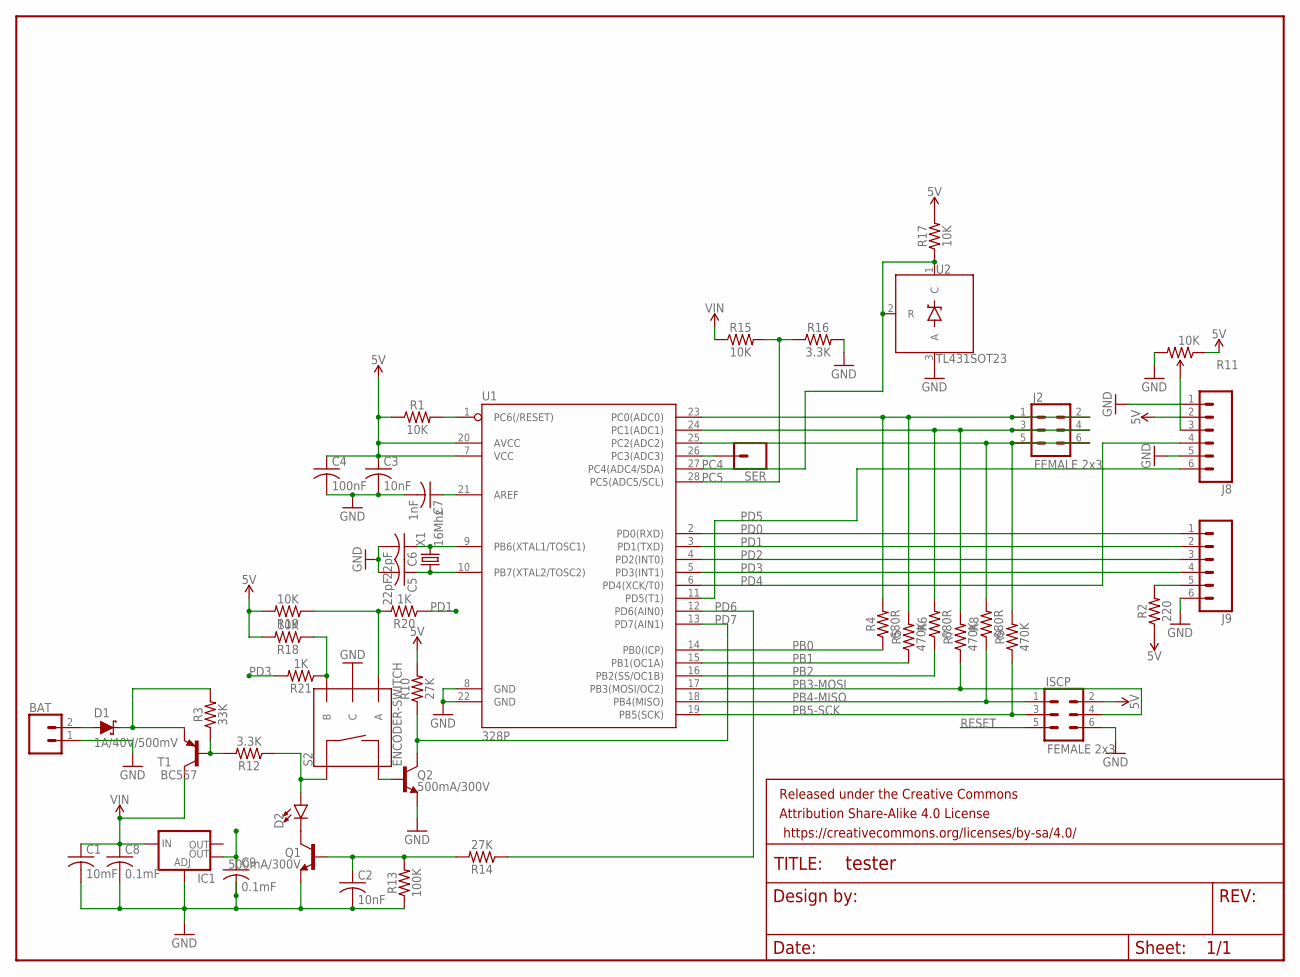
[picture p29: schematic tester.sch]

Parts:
BAT: CONN_02; 1X02
C1: 10mF; C0805
C2, C3: 10nF; C0805
C4: 100nF; C0805
C5, C6: 22pF; C0805
C7: 1nF; C0805
C8, C9: 0.1mF; C0805
D1: 1A/40V/500mV; SMA-DIODE
D2: LED3MM; LED_3MM
FRAME1: FRAME-LETTER; CREATIVE_COMMONS
IC1: V_REG_LM1117SOT223; SOT223
ISCP: FEMALE 2x3; 2X3
J2: FEMALE 2x3; 2X3
J8, J9: CONN_06SILK_FEMALE_PTH; 1X06
Q1, Q2: 500mA/300V; SOT23-3
R1, R17, R18, R19: 10K; 0805
R2: 220; 1206
R3: 33K; 1206
R4, R6, R8: 680R; AXIAL-0.3
R5, R7, R9: 470K; AXIAL-0.3
R10, R14: 27K; 1206
R11: 10K; TRIM_POT_PTH
R12, R16: 3.3K; 1206
R13: 100K; 0805
R15: 10K; 1206
R20, R21: 1K; 0805
S2: ENCODER-SWITCH; ROTARY_ENC_PLAIN
SER: CONN_01; 1X01
T1: BC557; TO92-EBC
U1: 328P; DIP28
U2: TL431SOT23; SOT23-3
X1: 16Mhz; HC49

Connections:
5V: C3.1, C4.1, C9.1, IC1.4 (OUT), ISCP.2, J8.2, R1.1, R2.1, R10.2, R11.1 (CCW), R17.2, R18.2, R19.2, U1.7 (VCC), U1.20 (AVCC)
GND: BAT.1, C1.2, C2.2, C3.2, C4.2, C5.2, C6.2, C7.2, C8.2, C9.2, IC1.1 (ADJ), ISCP.6, J8.1, J8.5, J9.6, Q1.2 (E), Q2.2 (E), R11.3 (CW), R13.1, R16.2, S2.C, U1.8 (GND), U1.22 (GND), U2.3 (A)
unnamed: C6.1, U1.9 (PB6(XTAL1/TOSC1)), X1.2
unnamed: C5.1, U1.10 (PB7(XTAL2/TOSC2)), X1.1
unnamed: C7.1, U1.21 (AREF)
unnamed: J9.5, R2.2
unnamed: J8.3, R11.2 (WIPER)
unnamed: D2.K (C), Q1.3 (C)
unnamed: R18.1, R21.1, S2.B
unnamed: BAT.2, D1.A
unnamed: R3.1, R12.2, T1.B
unnamed: C2.1, Q1.1 (B), R13.2, R14.2
unnamed: D1.C, R3.2, T1.E
unnamed: D2.A, R12.1, S2.SW+
unnamed: R19.1, R20.2, S2.A
unnamed: Q2.1 (B), S2.SW-
PB0: R4.P$1 (1), U1.14 (PB0(ICP))
PB1: R5.P$1 (1), U1.15 (PB1(OC1A))
PB2: R6.P$1 (1), U1.16 (PB2(SS/OC1B))
PB3-MOSI: ISCP.4, R7.P$1 (1), U1.17 (PB3(MOSI/OC2))
PB4-MISO: ISCP.1, R8.P$1 (1), U1.18 (PB4(MISO))
PB5-SCK: ISCP.3, R9.P$1 (1), U1.19 (PB5(SCK))
PC4: R17.1, U1.27 (PC4(ADC4/SDA)), U2.1 (C), U2.2 (R)
PC5: R15.2, R16.1, U1.28 (PC5(ADC5/SCL))
PD0: J9.1, U1.2 (PD0(RXD))
PD1: J9.2, R20.1, U1.3 (PD1(TXD))
PD2: J9.3, U1.4 (PD2(INT0))
PD3: J9.4, R21.2, U1.5 (PD3(INT1))
PD4: J8.4, U1.6 (PD4(XCK/T0))
PD5: J8.6, U1.11 (PD5(T1))
PD6: R14.1, U1.12 (PD6(AIN0))
PD7: Q2.3 (C), R10.1, U1.13 (PD7(AIN1))
RESET: ISCP.5, R1.2, U1.1 (PC6(/RESET))
SERIAL: SER.1, U1.26 (PC3(ADC3))
TP1: J2.1, J2.2, R4.P$2 (2), R5.P$2 (2), U1.23 (PC0(ADC0))
TP2: J2.3, J2.4, R6.P$2 (2), R7.P$2 (2), U1.24 (PC1(ADC1))
TP3: J2.5, J2.6, R8.P$2 (2), R9.P$2 (2), U1.25 (PC2(ADC2))
VIN: C1.1, C8.1, IC1.3 (IN), R15.1, T1.C

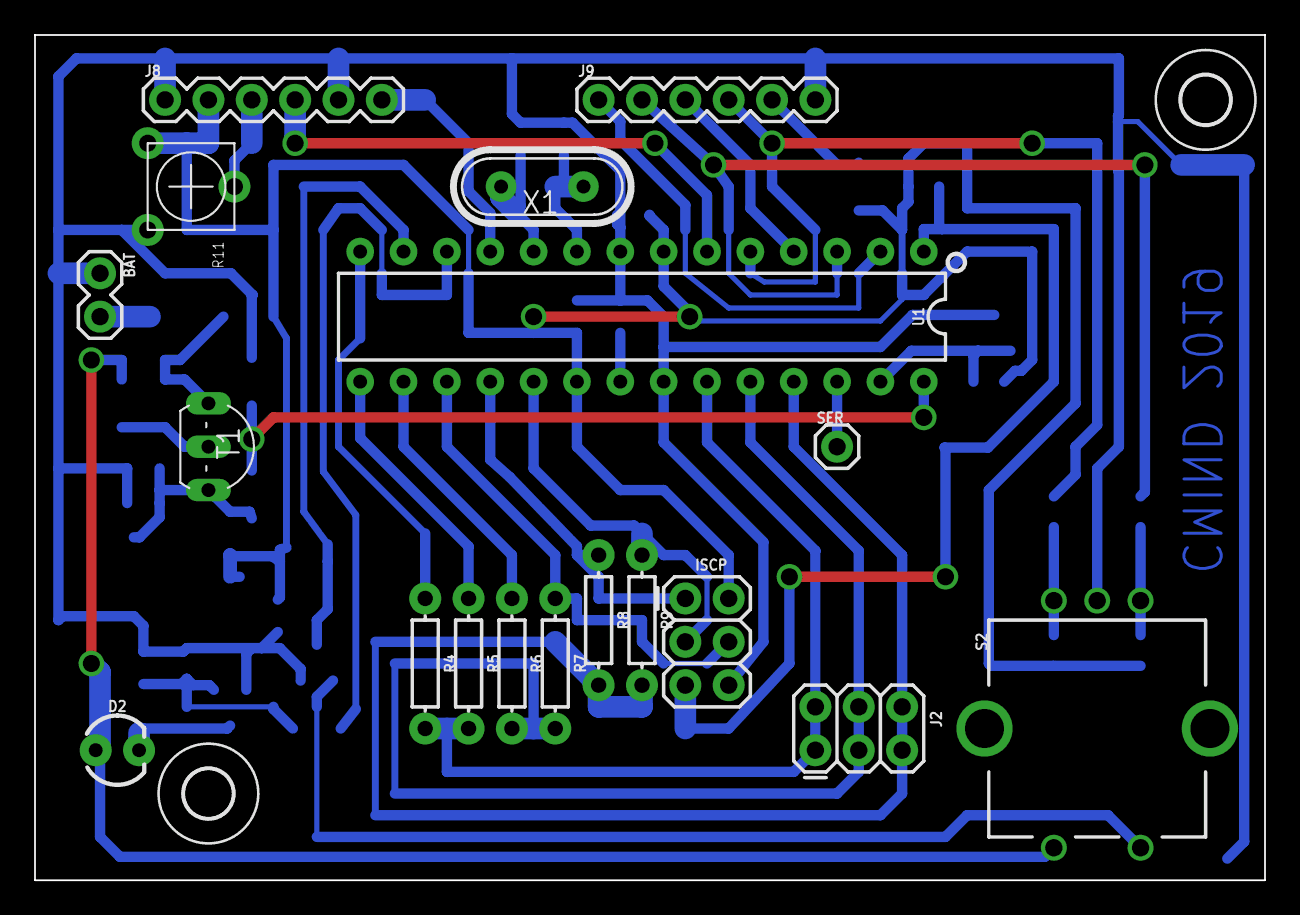
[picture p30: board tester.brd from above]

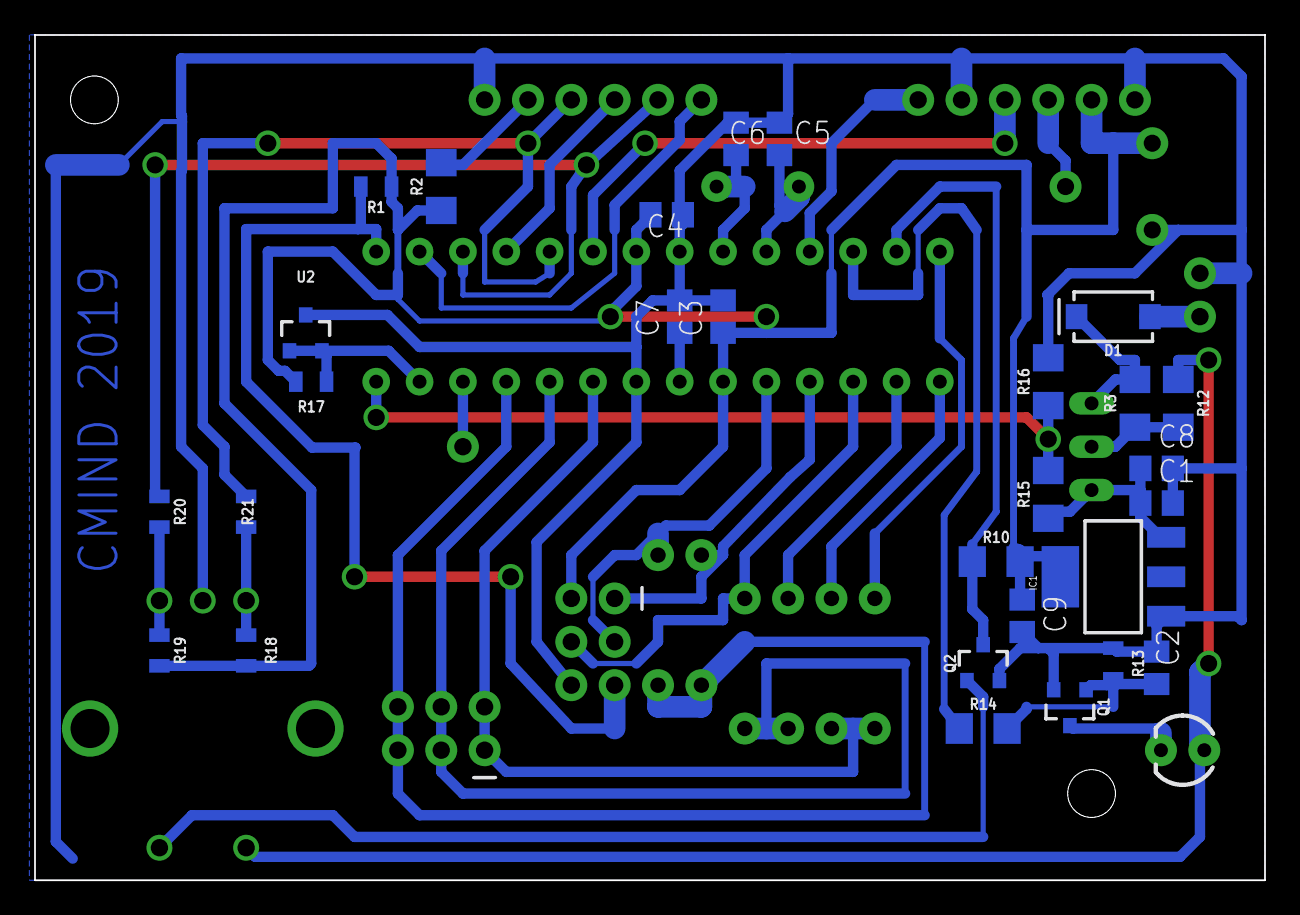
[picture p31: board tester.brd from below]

Board: 2 copper layers, 72.1 x 49.5 mm, 49 parts (28 on the bottom side), 38 nets.

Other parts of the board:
U$1, U$2: 2,8

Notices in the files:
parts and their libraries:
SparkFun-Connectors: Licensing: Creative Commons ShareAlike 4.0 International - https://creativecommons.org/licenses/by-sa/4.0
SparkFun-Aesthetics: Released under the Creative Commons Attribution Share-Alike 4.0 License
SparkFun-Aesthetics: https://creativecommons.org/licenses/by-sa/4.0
